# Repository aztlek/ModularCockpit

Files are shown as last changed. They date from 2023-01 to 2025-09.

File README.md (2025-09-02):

# Modular Cockpit for Star Citizen

The `Modular Cockpit` is a system of physical controls for *Star Citizen*. 

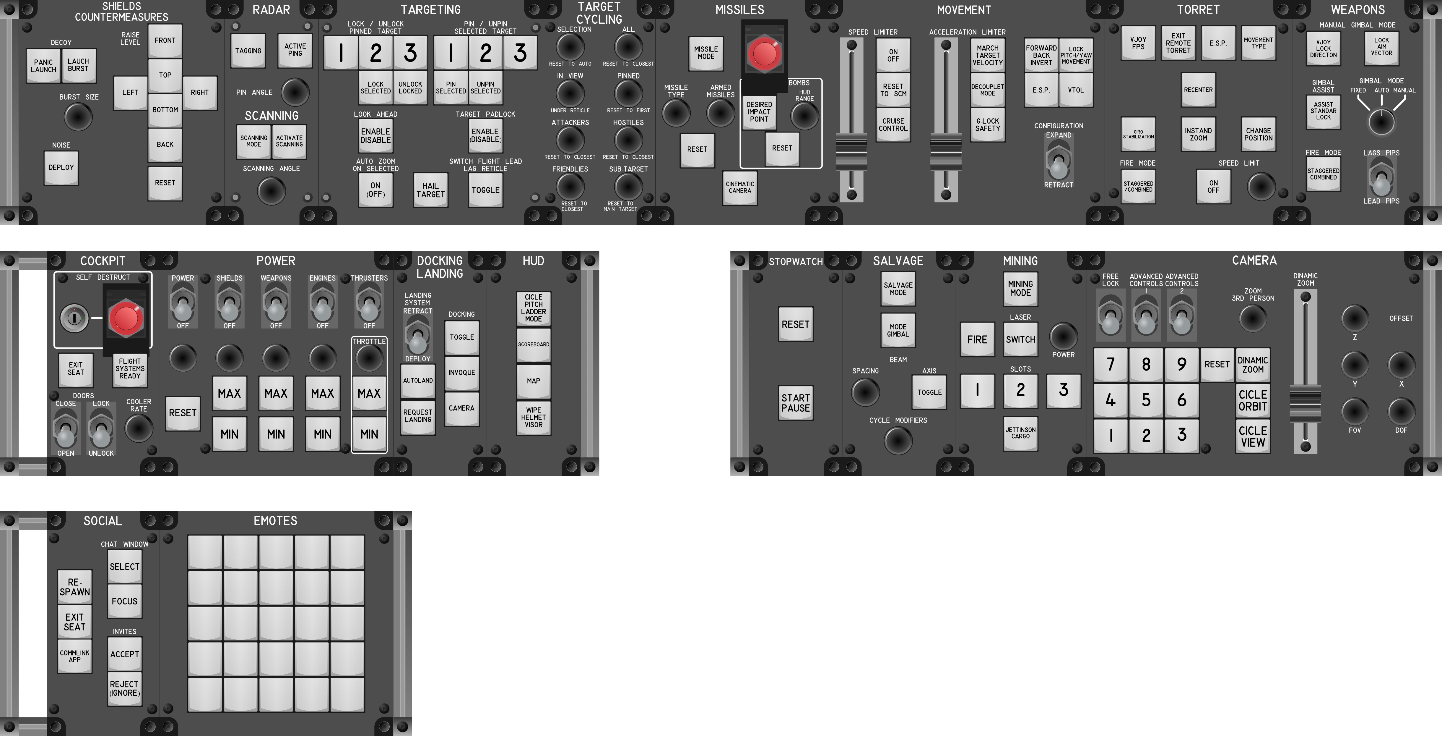
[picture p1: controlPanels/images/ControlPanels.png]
Star Citizen Modular Cockpit


It is composed of `Modules` that group several interrelated physical controls such as *switches*, *potentiometers*, *encoders*, etc. For example, the `Power Module` has several *toggle switches* to activate or deactivate power for weapons, shields, or others; it also has *encoders* to increase and decrease power, as well as buttons to quickly set maximum or minimum power.

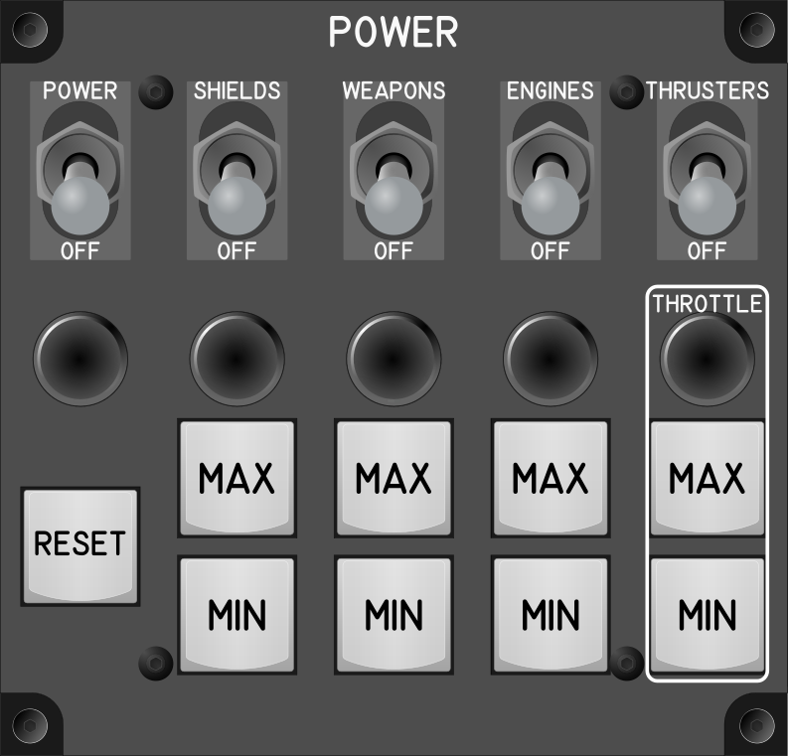
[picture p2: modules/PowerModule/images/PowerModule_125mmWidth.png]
Power Module


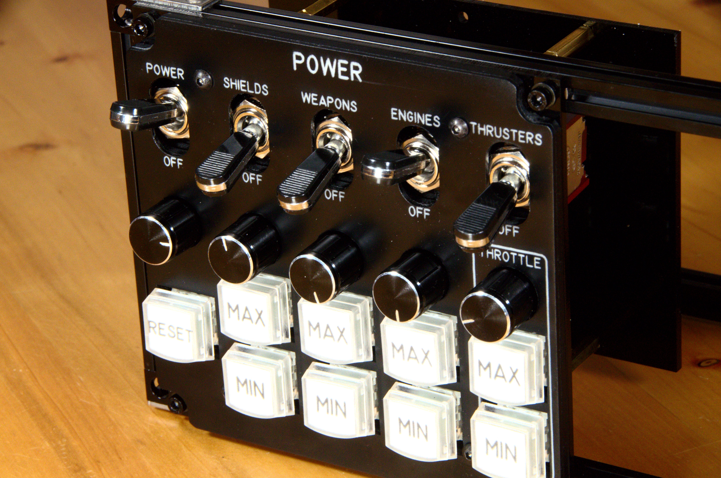
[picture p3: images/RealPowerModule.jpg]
Real Power Module


These `Modules` can be connected directly to the computer's USB port and the operating system sees them as a joystick, which makes it easy to perform *keybinding* in *Star Citizen*.

You can also `dock` several `Modules` to a `Control Panel`, which in turn connects to a computer USB port. When multiple `Modules` are docked to a `Control Panel`, the computer sees them all as a single joystick. This is very convenient when having a large number of `Modules` connected, preventing the operating system from failing in recognition and operation of multiple joysticks.

The `Modules` are interchangeable, meaning they can be swapped between `Control Panels` or positions within it. This way, the player can easily configure their cockpit depending on their playstyle.

Also, and very importantly, the `Modular Cockpit` is a free hardware and free software project. This means that anyone can download the designs and firmware, and build their own cockpit. They can also use it for whatever they want. In addition, they are free to study how the `Modular Cockpit` is made and modify it for their needs. Finally, they are free to redistribute it with or without changes as long as they state where it came from and who the authors are.

## Motivations

1. [Star Citizen](https://robertsspaceindustries.com/star-citizen/) is a game with highly enriched functionality and interactivity.
1. Each ship in *Star Citizen* can perform one or more roles.
1. Each player in *Star Citizen* can play one or more roles.
1. Each role has a particular form of interactivity.
1. Each player has a different way of playing.

Therefore, each player needs a unique cockpit adapted to their playstyle. A modular, open, and adaptable cockpit is needed for *Star Citizen*.

### Definitions

<dl>

<dt>Pilot:</dt>
<dd>The user of the <i>Modular Cockpit</i>, its very reason for existing.</dd>

<dt>Component:<dt>
<dd>The atoms that make up the <i>Modular Cockpit</i>. They can be electronic components, such as switches, potentiometers, cables, diodes, microcontrollers; or mechanical ones, such as acrylic sheets, makerbeams, etc.</dd>

<dt>Physical Control:<dt>
<dd>A type of electronic <i>Component</i> through which the <i>Pilot</i> interacts with <i>Star Citizen</i>. For example, switches, buttons, encoders, potentiometers, etc.</dd>

<dt>Module:</dt>
<dd>A grouping of physical controls and components with related functions.</dd>

<dt>Control Panel</dt>
<dd>A structure made with <a href="https://www.makerbeam.com/makerbeam/">10x10 mm Makerbeam</a> (see <i>Frame</i>) where one or several <i>Modules</i> can be <i>docked</i>.</dd>

<dt>Frame:<dt>
<dd>This is a structure built with <a href="https://www.makerbeam.com/makerbeam/">10x10 mm Makerbeam</a>. It has a height of 120 mm and the required width. For this, <a href="https://www.makerbeam.com/makerbeam-100mm-16p-black-makerbeam.html"><i>100 mm vertical beams</i></a> are used and joined to the <a href="https://www.makerbeam.com/makerbeam/10x10mm-profiles-black/"><i>horizontal beams</i></a> with <a href="https://www.makerbeam.com/makerbeam-corner-cubes-12p-black-for-makerbeam.html">MakerBeam Corner Cubes</a>. Several <a href="https://www.makerbeam.com/makerbeam-t-slot-nuts-for-makerbeam-25p.html">T-slot nuts</a> are inserted into the horizontal beams, where the <i>Modules</i> are screwed in with M3 bolts. Any other compatible system can be used. For example, the following image shows a <i>Frame</i> 220 mm wide with its different parts.</dd>

<dt>Docking a Module</dt>
<dd>Physically placing a <i>Module</i> into a <i>Control Panel</i> so that it is fixed and connected.</dd>

<dt>Undocking a Module</dt>
<dd>Removing a <i>Module</i> from the <i>Control Panel</i>, leaving the slot free.</dd>

</dl>

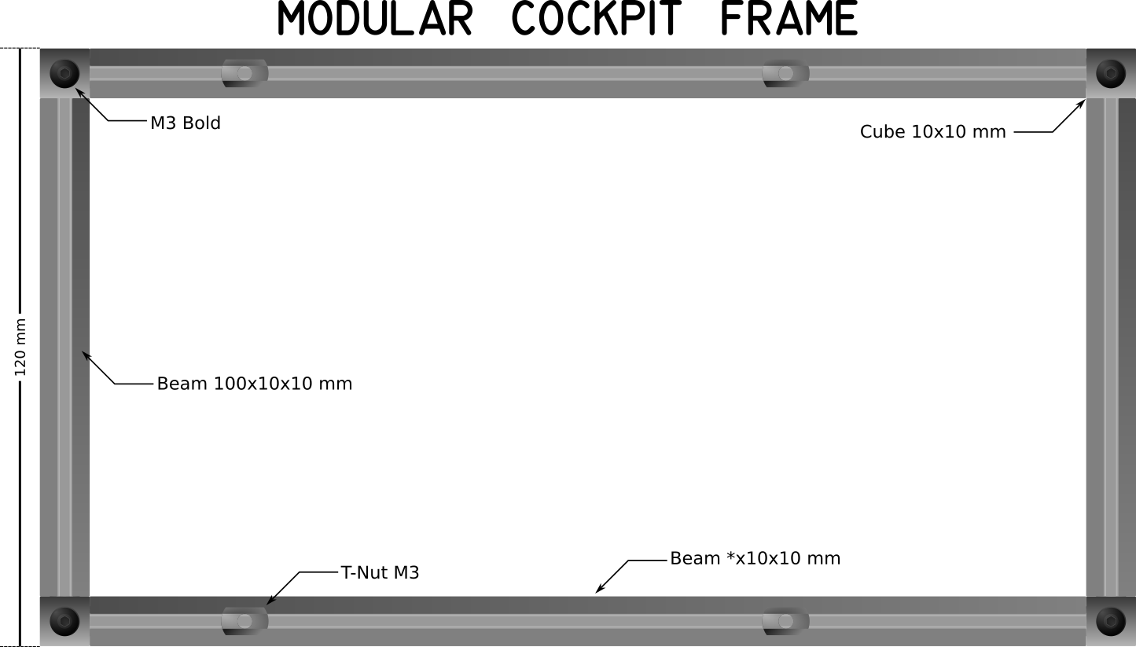
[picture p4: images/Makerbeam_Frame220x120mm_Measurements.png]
Frame with measurements


## Design Requirements

### Design Requirements for `Modules`

1. Each `Module` must work independently: it should not require other modules or elements to function, except the computer.
1. It must be interchangeable, meaning it can be placed in any `ControlPanel` and work.
1. A module must have only one cable connected to it: the USB cable.
1. A `Module` must be screwable to the `Frame` of a `ControlPanel`.
1. A module groups several related functions. The grouping of these functions must follow the categorization given in the *Keybinding* of *Star Citizen*. For example, there is a *Vehicles - Cockpit* category, so there will be at least one module that covers that category.
1. The aesthetics of the `Modules` must resemble those of military aircraft. See [The Warthod Project](https://thewarthogproject.com/) as a reference.
1. Particular functions, such as backlighting, must work within the `Module`. If there is no dedicated control for this function, it must be controllable from the computer or from a `Control Panel` independently. 

### Design Requirements for Control Panels

1. The front part of a `ControlPanel` is a `Frame` as defined above.
1. Each `ControlPanel` must have only two cables connected to it: the USB cable and the power cable.
1. The `Modules` connected to the `Control Panel` must be seen by the computer as if they were a single joystick. This avoids errors and problems caused by connecting many joysticks simultaneously.
1. A `Control Panel` can centralize particular functions of a `Module`, such as backlighting, to make global changes to these functions.
1. A `Control Panel` controls the ventilation function, which the `Modules` do not handle.

## Modules

1. [Salvage Module](modules/SalvageModule)
1. [Missiles Module](modules/MissilesModule)
1. [Docking and Landing Module](modules/DockingLandingModule)
1. [Shields and Countermeasures Module](modules/ShieldsCountermeasuresModule)
1. [Emotes Module](modules/EmotesModule)
1. [Movement Module](modules/MovementModule)
1. [Weapons Module](modules/WeaponsModule)
1. [Target Cycling Module](modules/TargetCyclingModule)
1. [Camera Module](modules/CameraModule)
1. [Stopwatch Module](modules/StopwatchModule)
1. [Power Module](modules/PowerModule)
1. [Targeting Module](modules/TargetingModule)
1. [Social Module](modules/SocialModule)
1. [Turret Module](modules/TorretModule)
1. [Mining Module](modules/MiningModule)
1. [Cockpit Module](modules/CockpitModule)
1. [Radar and Scanning Module](modules/RadarScanningModule)
1. [Hud Module](modules/HudModule)

## Input Devices

There are several types of input devices:

<dl>

<dt>Mechanical keyboard keys:</dt>
<dd>Mechanical keyboard keys are used for most SC keybindings, since SC is designed around keys.</dd>

<dt>Encoder</dt>
<dd>For cases where there are two keys, one for increasing and another for decreasing the same value, such as increasing or decreasing shield energy.</dd>

<dt>Toggle Switch (ON/OFF)</dt>
<dd>These are used when there are two keys, one to turn on and another to turn off, for example, turning shields on and off.</dd>

<dt>Linear Potentiometer</dt>
<dd>These are used for cases where SC has associated axes, or absolute changes of a value.</dd>

<dt>Joystick</dt>
<dd>Apart from obvious cases where joysticks are used, there are keybindings that by their nature should be controlled with a joystick. A joystick is essentially (at least) two orthogonal potentiometers, allowing control of two orthogonal absolute variables, such as z/y displacement of the camera.</dd>

<dt><a href="https://www.cirque.com/glidepoint-circle-trackpads">GlidePoint® Circle Trackpads</a> (like the Steam Controller)</dt>
<dd>This trackpad works very similarly to an analog joystick, so it can be used for the same purposes.</dd>

</dl>

## Microcontroller

[Teensy®](https://www.pjrc.com/teensy/) is used for the following reasons:

1. It can function as multiple HID devices simultaneously: it can be a keyboard, joystick, and mouse at the same time, in addition to working with serial. This last feature is necessary to implement a communication protocol with the modules, or in case *Star Citizen* implements something similar to *DCS-BIOS*. Being able to have both keyboard and joystick simultaneously is necessary, for example, for the ```CameraModule```, since *Star Citizen* has no way to map joystick buttons to advanced camera functions and those can only be mapped to keyboard and mouse.
1. It has many input pins. In the case of the *Teensy 4.0*, there are 40 digital pins and 14 analog ones. In the *Teensy 4.1*, there are 55 digital inputs and 18 analog ones. This is necessary since some modules require many inputs, such as the `TargetCyclingModule` with 24 digital inputs or the `PowerModule` with 30 digital inputs.
1. Furthermore, all digital inputs have interrupt capability. This makes input reading much faster. For example, the `TargetCyclingModule` with many encoders is much faster thanks to interrupt capability.
1. It also has many PWM outputs. In the case of the *Teensy 4.0*, there are 31. In the case of the *Teensy 4.1*, there are 35. This is very important for managing the backlighting of the modules.
1. The *Teensy 4.1* has a *USB Host* port used in `Control Panels` to unify the `Modules` so the operating system sees them as a single joystick.
1. It has very good speed, making the *Teensy 4.1* preferable for unifying the modules in the `ControlPanel`.
1. It also has a good amount of memory, which makes this not a concern when coding.

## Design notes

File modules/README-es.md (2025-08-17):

# Módulos

## Cómo crear un joystick personalizado especial para el modular joystick

### Adicionar un ```USB Type```al Teensy 4.0

1. Edite al archivo ```boards.txt```que se encuentra en la ruta ```~/.arduino15/packages/teensy/hardware/avr/1.59.0``` en Linux .
1. Inserte en después de la linea ```teensy40.menu.usb.flightsimjoystick.fake_serial=teensy_gateway``` las siguientes líneas:
	```
	teensy40.menu.usb.customcontroller=Modular Cockpit Joystick
	teensy40.menu.usb.customcontroller.build.usbtype=MODULAR_COCKPIT_JOYSTICK
	teensy40.menu.usb.customcontroller.upload_port.usbtype=MODULAR_COCKPIT_JOYSTICK
	```	
1. Guardar y salir

### Definir un nuevo tipo de USB

1. Edite el archivo ```usb_desc.h``` que se encuentra en la ruta ```~/.arduino15/packages/teensy/hardware/avr/1.59.0/cores/teensy4```en Linux.
1. Inserte el siguiente código antes de la línea ```#elif defined(USB_SERIAL_HID)```
	```
	 #elif defined(MODULAR_COCKPIT_JOYSTICK)
	  #define VENDOR_ID		0x16C0
	  #define PRODUCT_ID		0x0487
	  #define MANUFACTURER_NAME	{'A','z','t','l','e','k',' ','G','a','m','e','s'}
	  #define MANUFACTURER_NAME_LEN	12
	  #define PRODUCT_NAME		{'M','o','d','u','l','a','r',' ','C','o','c','k','p','i','t',' ','J','o','y','s','t','i','c','k'}
	  #define PRODUCT_NAME_LEN	24
	  #define EP0_SIZE		64
	  #define NUM_ENDPOINTS		4
	  #define NUM_INTERFACE		3
	  #define CDC_IAD_DESCRIPTOR	1
	  #define CDC_STATUS_INTERFACE	0
	  #define CDC_DATA_INTERFACE	1	// Serial
	  #define CDC_ACM_ENDPOINT	2
	  #define CDC_RX_ENDPOINT       3
	  #define CDC_TX_ENDPOINT       3
	  #define CDC_ACM_SIZE          16
	  #define CDC_RX_SIZE_480       512
	  #define CDC_TX_SIZE_480       512
	  #define CDC_RX_SIZE_12        64
	  #define CDC_TX_SIZE_12        64
	  #define JOYSTICK_INTERFACE    4	// Joystick
	  #define JOYSTICK_ENDPOINT     4
	  #define JOYSTICK_SIZE         64	//  12 = normal, 64 = extreme joystick
	  #define JOYSTICK_INTERVAL     1
	  #define ENDPOINT2_CONFIG	ENDPOINT_RECEIVE_UNUSED + ENDPOINT_TRANSMIT_INTERRUPT
	  #define ENDPOINT3_CONFIG	ENDPOINT_RECEIVE_BULK + ENDPOINT_TRANSMIT_BULK
	  #define ENDPOINT4_CONFIG	ENDPOINT_RECEIVE_UNUSED + ENDPOINT_TRANSMIT_INTERRUPT
	```
1. 	Guardar y salir.

### Crear el descriptor USB HID

No se hizo nada por que se usó el de 64, el ```extreme joystick```.

### Modificar la librería ```usb_joystick```

No se hizo nada por que se usó el de 64, el ```extreme joystick```.

### Reconfigurar y reniciar el IDE de Arduino

1. Salir del IDE de Arduino.
1. Borrar el directorio ```arduino-ide``` que está en
	1. En linux ```~/.config/arduino-ide/```
	1. En windows ```C:\Users\<user name>\AppData\Roaming\arduino-ide\ ```
	1. En MacOS ```~/Library/Application Support/arduino-ide/```
1. Reiniciar el IDE de Arduino.

### Referencias de Cómo crear un joystick personalizado

1. [Create a Custom Joystick With Teensy 4.1](https://www.instructables.com/Create-a-Custom-Joystick-With-the-Teensy-41/)
1. [Changes to custom board option definitions in boards.txt are not picked up #1030](https://github.com/arduino/arduino-ide/issues/1030#issuecomment-1152005617)

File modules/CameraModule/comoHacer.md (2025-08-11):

## How to make the Camera Module

### Bill of materials

### Corte, pintura y grabado

1. Cortar las capas usando los diagramas de corte [Cuts](images/cut/PDF)
1. Pegar la capa frontal y la media.
1. Pintar las capa frontal y media:
    1. Enmascarar con la masking tape la perte de atraz de la middle layer.
    1.  Lijar.
    1. Aplicar Primer.
    1. Pintar.
    1. Dejar secar.
1. Grabar la capa frontal pintada usando el diagrama de engrave [Engraves](images/engrave)

### Montar el Teensy 4.0 en su breakout

1. Soldar los pines
1. Colocar el Teensy en el breakout.

### Ensamblado de componentes

1. Poner los componentes en la back layer.
1. Colocar el Teensy 4.0:
    1. Soldar los pines.
    1. Colocar el Teensy en el breakout.
    1. Atornillar el breackout a la layer del microcontrolador con:
        * los 2 Button Head Socket Cap Bolts M3x12, 
        * 2 M3 Flat Washers y
        * 2 M3 Hexagon Hex Nut.

### Hacer la parte electrónica

1. Soldar los diferentes cables según el diagrama:
  Drawing Connections
1. Hacer gestión de cables con los Cable Zip Ties.

### Ensamblado del módulo

1. Ensamblar los front panels usando:
    * Front panel y Middle panel pegados.
    * Back panel.
    * 4 female to Female Thread Spacer Screws Brass Hex Standoff M3 x 60mm.
    * 4 3M Flat Washers.
    * 4 3Mx5 Button Head Socket Cap Bolts.
1. Ensamblar el microcontroler panel usando:
    * Lo que ya está essamblado del módulo.
    * 4 3M Flat Washers.
    * 4 3Mx5 Button Head Socket Cap Bolts.

### Imprimir y colocar los labels de los keycaps

1. Imprimir los labels de las keycaps usando el diagrama: [Key Labels](images/ModuleKeyLabels.pdf)
1. Ponler los labels en las keyscaps.
1. Poner las keyscaps y en las keys.

### Ensamblar en el Central Control Panel

1. Ensamblar en el Central Control Panel usando lo siguiente:
    * 4 3Mx6 Socket Head Cap Bolts.
    * 4 3M Flat Washers.

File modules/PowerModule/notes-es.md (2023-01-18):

# Modulo de potencia (PowerModule)

Power Module

El módulo de potencia tiene los controles para la de administración de la
potencia en vuelo como para los de vehículos.

## Keybindings

Los keybindingd a considerar para este módulo pertenecen a dos categorias en SC
`Vehicles – Power Triangle  Assignement` y `Flight – Power`.

### Vehicles – Power Triangle  Assignement

| Keybinding | Tipo de dispositivo de entrada |
| --- | --- |
| Weapons – Increase (tab) | encoder[0]: increase |
| Weapons – Decrease (tab) | encoder[0]: decrease |
| Weapons – Set to Max (tab) | key[0]  |
| Weapons – Set to Min (tab) | key[1] |
| Engines – Increase (tab) | encoder[1]: increase  |
| Engines – Decrease (tab) | encoder[1]: decrease |
| Engines – Set to Max (tab) | key[2] |
| Engines – Set to Min (tab) | key[3] |
| Shields – Increase (tab) | encoder[2]: increase |
| Shields – Decrease (tab) | encoder[2]: decrease |
| Shields – Set to Max (tab) | key[4] |
| Shields – Set to Min (tab) | key[5] |
| Reset Assignements | key[6] |

### Flight – Power

| Keybinding | Tipo de dispositivo de entrada |
| --- | --- |
| Set Power On | toggle_switch[0]: on |
| Set Power Off | toggle_switch[0]: off |
| Set Thrusters Power On | toggle_switch[1]: on |
| Set Thrusters Power Off | toggle_switch[1]: off |
| Set Shields Power On | toggle_switch[2]: on |
| Set Shields Power Off | toggle_switch[2]: off |
| Set Weapons Power On | toggle_switch[3]: on |
| Set Weapons Power Off | toggle_switch[3]: off |
| Increase Throttle | encoder[3]: increase |
| Decrease Throttle | encoder[3]: decrease |
| Increase Throttle to Max (double tab) | key[7] |
| Decrease Throttle to Min (double tab) | key[8] |

### Total de dispositivos usados en los keybindings

| Dispositivo | Numero |
| --- | -----: |
| Keys | 9 |
| Toggle switchs | 4 |
| Encoders | 4 |

### Categorización

La siguiente tabla organiza en dos categorias ortogonales los dispositivos de
entrada. Es una primera aproximación a como deben quedar organizados en el
panel del módulo los dispositivos de entrada.

| Power | Shields | Weapons | Engines | Thrusters | Throttle |
| :--- | :---: | :---: | :---: | :---: | :---: |
| toggle_switch | toggle_switch | toggle_switch | toggle_switch | toggle_switch | |
| | encoder | encoder | encoder | | encoder |
| | key (Max) | key (Max) | key (Max) | | key (Max) |
| | key (Min) | key (Min) | key (Min) | | key (Min) |
| key (reset) | | | | | |

## Diseño

### Consideraciones

1. Las columnas `Thrusters` y `Throttle` se fusionaron en una, pero
   marcando la diferencia entre un grupo y otro.
1. La tecla de `reset` se integra a la matriz principal de teclas debajo
   del `toggle_switch` del power.

## Componentes y procesos

Inventario de componentes y procesos para armar el módulo.

| Componente o proceso | Cantidad |
| --- | ---: |
| Keys | 9 |
| Toggle switchs | 4 |
| Encoders | 4 |
| Microcontrolador | 1 |
| Cable USB | 1 |
| Acrilico negro | 1 |
| Acrilico blanco | 1 |
| Acrilico translucido | 1 |
| Tornillos allen M3 cabeza del botón negros | ?? |
| Tornillos allen M3 cabeza de enchufe negros  | 4 |
| Standoff M3 | ?? |
| Tuercas Makerbeam | 4 |
| Cables de colores para soldar | ?? |
| Termiencogible de colores | ?? |
| Terminales para prensar los toggle switch | ?? |
| Lata de pintura negra de acrilico | 1 |
| Pegante para acrilico | 1 |
| Corte laser para los acrilicos | 3 |
| Grabado laser | 1 |

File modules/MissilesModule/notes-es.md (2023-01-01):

# Módulo de Misiles (Missiles Module)

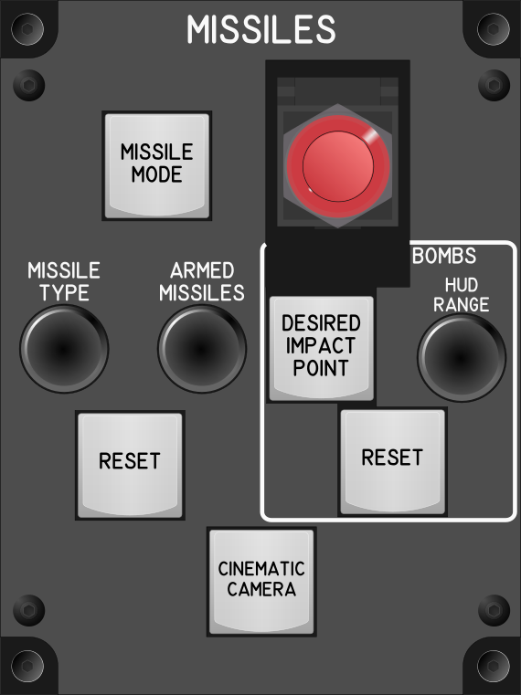
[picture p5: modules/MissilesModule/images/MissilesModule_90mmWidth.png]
Missiles Module


## Keybindings

| Keybinding | Tipo de dispositivo de entrada |
| ---| ---|
| Launch Missiles | key[0] |
| Cycle Next Missile Type | encoder[0]: increase |
| Cycle Previous Missile Type | encoder[0]: decrease |
| Increase Number of Armed Missiles | encoder[1]: increase |
| Decrease Number of Armed Missiles | encoder[1]: decrease |
| Reset Number of Armed Missiles | key[1] |
| [PH] Bombs Toggle Desired Impact Point | key[2] |
| Bombs - Increase HUD Range | encoder[2]: increase |
| Bombs – Decrease HUD Range | encoder[2]: decrease |
| Bombs – Reset HUD Range | key[3] |
| [PH] Enable Cinematic Camera (toggle)  | key[4] |

### Total de dispositivos usados en los keybindings

| Dispositivo | Numero |
| --- | -----: |
| Keys | 5 |
| Toggle switchs | 0 |
| Encoders | 3 |

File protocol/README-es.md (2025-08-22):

# Protocolo de comunicación por el serial de los modules, controlPanels e interfaz gráfica

Este protocolo se implementa sobre el serial de los módulos y de los paneles de control.

## Mensajes del Module

* Como los módulos pueden conectarse directamente al computador o mediante un ControlPanel los mensajes que le llegan son indiferentes si llegan de la interfaz gráfica o del ControlPanel. Por eso hay una columna en la siguiente tabla en el que disparador puede llegar de la interfa gráfica o del ControlPanel.
* Los mensajes de debug comienzan con una 'D' amyúscula, que viene a ser en byte 0, para diferenciarlos de los otros tipos de mensajes.

| Mensaje | Valor Byte 0 | Tipo parámetro | Valor | Disparador en el Module  | Disparador desde el ControlPanel o Interfáz Gráfica | Descripción |
| --- | ---: | --- | ----- | --- | --- | --- |
| Change_debug_mode | 1 | byte | 0,1 | Toggle Buttom | Change_debug_mode | Cambia el modo de debug 0 no debug, 1 debug |
| Change_backlight_brightness | 2 | byte | 0-255 | Potentiometer | Change_backlight_brightness | Cambia el brillo de la retroilumimación |
| Change_fan_speed | 3 | byte | 0-255 | Potentiometer | | Cambia la velocidad del ventilador. |
| Send_names | 11 | string | | | Ask_names | Envía el nombre del Module |
| Send_number_buttons | 21 | byte | 0-128 | | Ask_number | Envía el número de botones |
| Send_number_axis | 23 | byte | 0-128 | | Ask_number | Envía el número de ejes |
| Send_debug_output | 'D' | string | | | Cambio en el estado de debug a 1 | Envía mensajes de debug si el debug está activo |

## Mensajes del ControlPanel

* El brillo de los módulos puede ser cambiado desde un módulo, o desde un potenciometro conectado directamente al ControlPanel o desde la Intefaz Gráfica.
* El estado del debug puede ser cambiado desde un módulo, o desde un toggle buttom conectado directamente al Control Panel o desde la Interfaz Gráfica.
* Por lo anterior la Intefáz Gráfica debe tener una parte donde se muestren los mensajes que llegan desde el serial.
* Los mensajes de debug comienzan con una 'D' amyúscula, que viene a ser en byte 0, para diferenciarlos de los otros tipos de mensajes.

| Mensaje | Valor Byte 0 | Tipo parámetro | Valor | Disparador en el ControlPanel  | Disparador desde el Module  | Disparador desde la Interfaz Gráfica  | Descripción |
| --- | ---: | --- | ----- | --- | --- | --- | --- |
| Change_debug_mode | 1 | byte | 0,1 | Toggle Buttom | Change_debug_mode | Change_debug_mode | Cambia el modo de debug 0 no debug, 1 debug |
| Change_backlight_brightness | 2 | byte | 0-255 | Potentiometer | Change_backlight_brightness | Change_backlight_brightness | Cambia el brillo de la retroilumimación de los modules conectados a ControlPanel, o de los controlPanles conectados a la Interfaz Gráfica  |
| Change_fan_speed | 3 | byte | 0-255 | Potentiometer | Change_fan_speed | Change_fan_speed | Cambia la velocidad del ventilador. |
| Ask_names | 10 | | | setup() | | Ask_names | Pregunta por el nombre del modulo desde el control panel, o del panel desde la Interfaz Gráfica |
| Send_names | 11 | string | | | | Ask_names | Envía el nombre del panel seguida por dos puntos y una lista separada por comas de los nombres de los Modules |
| Ask_numbers | 20 | | | setup() | | Ask_number | Pregunta por el numero de componentes desde el ControlPanel, o número de modules desde la Interfáz Gráfica |
| Send_number_modules | 22 | byte | 0-9 | | | Ask_number | Envía el número de modulos coectados a ControlPanel |
| Send_debug_output | 'D' | string | | El estado de debug == 1 | | | Envía mensajes de debug si el debug está activo |

## Mensajes

### Setup modules

En el Setup se le pregunta a cada módulo su nombre, numero de teclas y de ejes.

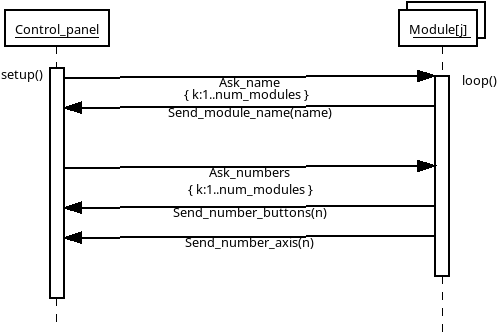
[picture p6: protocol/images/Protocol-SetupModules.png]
Setup modules


### Change_debug_mode

El mensaje Change_debug_mode cambia el modo de debug, si se envia un 1 se activa la impresión de mensajes de menú, si se envía un 0 se desactiva.

#### Change_debug_mode from Module without Control panels

El piloto cambia el estado de debug de todos los módulos conectados al computador mediante un toggle buttom que está conectado al módulo. Esto permite dos cosas: Tener un botón en cualquiera de los módulos. Tener un módulo especialisado de setup que tenga en toggle buttom de debug.

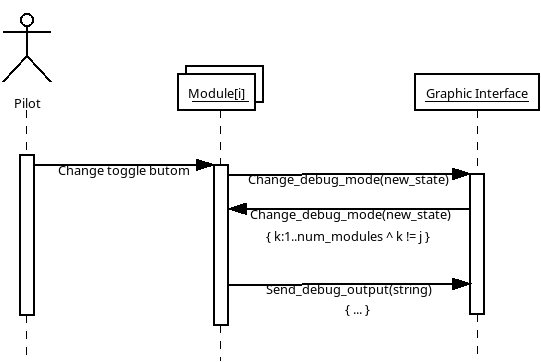
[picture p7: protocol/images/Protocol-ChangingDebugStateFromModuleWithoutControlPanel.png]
Change_debug_mode from Module without Control panel


#### Change_debug_mode from Graphic Interface without Control panels

El piloto cambia el estado de debug de todos los módulos conectados al computador, pero mediante toggle buttom en la interfaz gráfica.

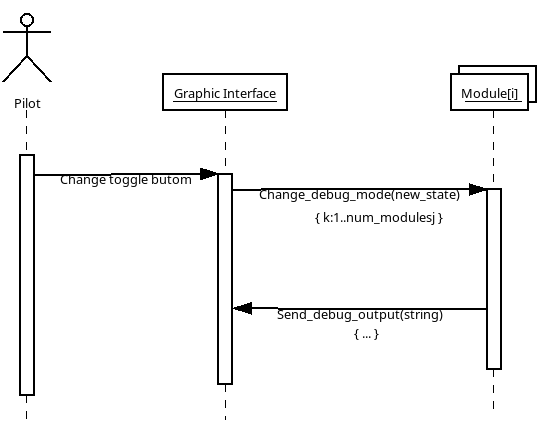
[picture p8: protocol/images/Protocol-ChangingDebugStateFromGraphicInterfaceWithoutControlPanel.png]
Change_debug_mode from Graphic Interface without Control panel


#### Change_debug_mode from Module

El piloto cambia el estado de debug de todos los módulos conectados al ControlPanel y todos los que están conectados al computador, pero mediante un toggle buttom que está conectado al Module. Si esta corriendo la interfaz gráfica cambia el estdo de todos los modulos conectados a los ControlPanels, o de los módulos conectados directo al computador.

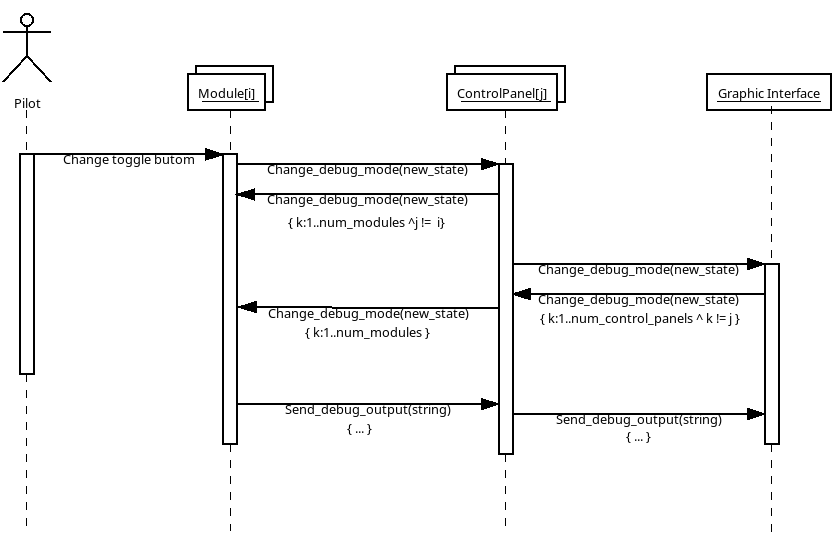
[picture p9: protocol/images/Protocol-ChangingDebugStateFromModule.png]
Change_debug_mode from Module


#### Change_debug_mode from Graphic Interface

El piloto cambia el estado de debug de todos los módulos conectados al ControlPanels que están conectados al computador, pero mediante un toggle buttom de la Interfaz Gráfica.

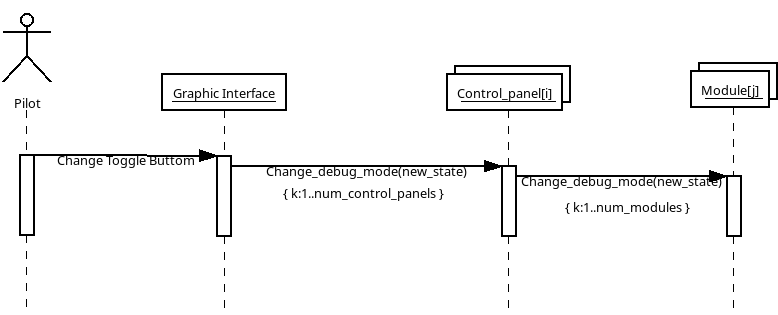
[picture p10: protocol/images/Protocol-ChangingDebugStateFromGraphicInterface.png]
Change_debug_mode from Graphic Interface


#### Change_debug_mode from ControlPanel

El piloto cambia el estado de debug de todos los módulos conectados al ControlPanel, pero mediante un toggle buttom que está conectado al ControlPanel. Si esta corriendo la interfaz gráfica cambia el estdo de todos los modulos conectados a los ControlPanels, o de los módulos conectados directo al computador.

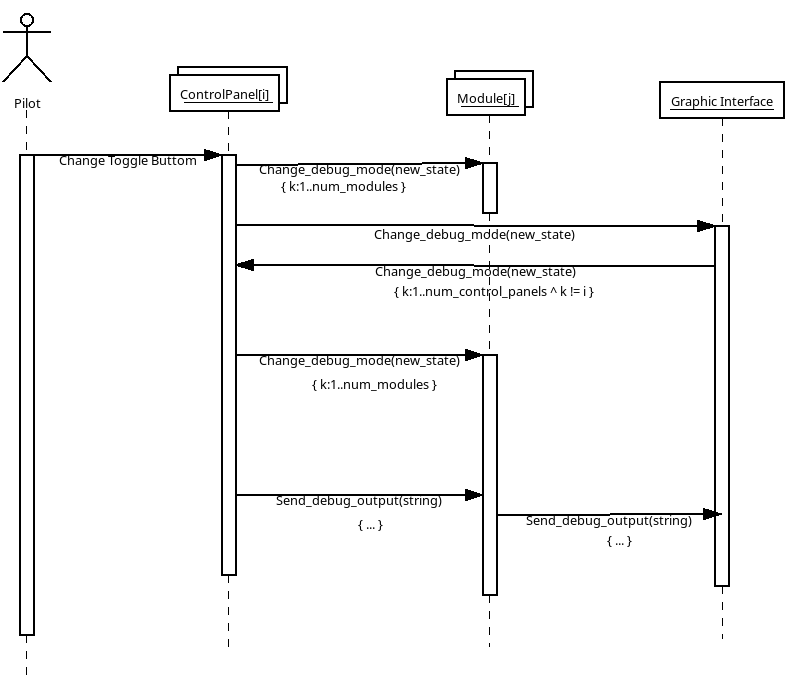
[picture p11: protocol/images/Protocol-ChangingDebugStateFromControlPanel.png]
Change_debug_mode from ControlPanel


### Change_backlight_brightness

Cambia el brillo de la retroiluminación de los módulos. La forma en como funciona este mensaje es casi igual que la de Change_debug_mode (pero sin el mensaje de Send_debug_output) por lo que no se presentam estos diagramas de interación.

### Change_fan_speed

Cambia la velocidad del el ventilador o ventiladores de ControlPanel. ESto se puede hacer mediante un potenciometro conectado directamante al ControlPanel, mediante un mensaje Change_fan_speed que llega de un módulo o de la GraphicInterface.

#### Change_fan_speed from ControlPanel

Cambia la velocidad del los ventiladores con un potenciometro conectado al ControlPanel. Sólo cambia la velocidad de sus propios ventiladores, por que los demás ControlPanels tiene diferentes necesidades de ventilación.

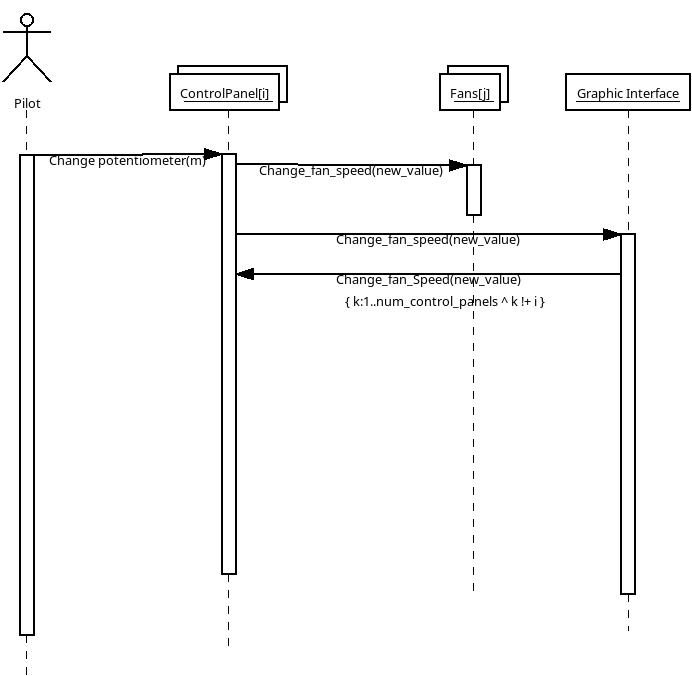
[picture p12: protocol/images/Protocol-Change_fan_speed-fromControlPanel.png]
change_fan_speed from ControlPanel


#### Change_fan_speed from GraphicInterface

Cambia la velocidad de los ventiladores de un ControlPanel selecionado en la interfaz desde la GraphicInterface. Sólo cambia la velocidad de los ventiladores de un ControlPanel selecionado, esto porque cada controlPanel tiene diferentes necesidades de ventilación.

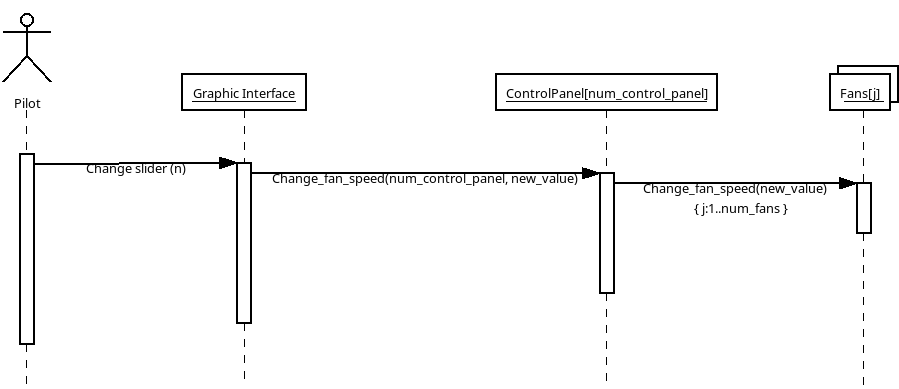
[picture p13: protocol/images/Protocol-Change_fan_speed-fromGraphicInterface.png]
Change_fan_speed from GraphicInterface


#### Change_fan_speed from Module

Cambia la velocidad del las ventiladores del ControlPanel al que está conectado el Module. Sólo cambia la velocidad de los ventiladores del ContolPanel al que está conectado el módulo, esto porque cada ControlPanel tiene sus necesidades particulares de ventilación

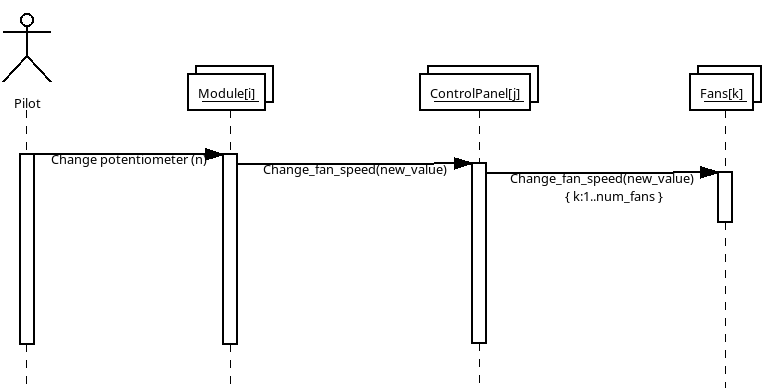
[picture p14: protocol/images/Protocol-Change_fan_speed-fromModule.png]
Change_fan_speed from Module


### Send_debug_output

Si el debug está a 1, se imprimen los mensajes de debug en el serial del módulo, y si está conectado al un ControlPanel esta los pasa con Control Panel he imprime sus propios mensajes, a contianuación la interfaz gráfica toma todos estos mensajes y los muestra. Se usa para mostar toda la informacion de paneles de control y modulos conectados.

### Ask_names

Se preguntan los nombres de los módulos y control panels con el fin de ser mostrados en la Interfa Gráfica.

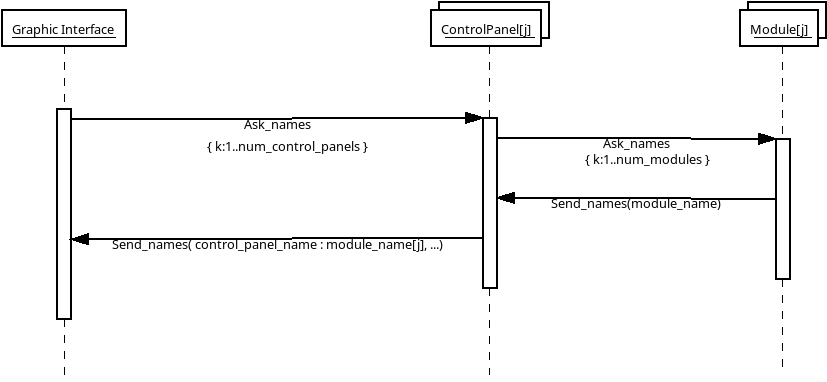
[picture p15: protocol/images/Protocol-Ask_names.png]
Ask_names


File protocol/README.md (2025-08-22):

# Serial communication protocol for modules, control panels, and graphical interfaces

This protocol is implemented over the serial port of modules and control panels.

## Module Messages

* Since modules can be connected directly to the computer or through a control panel, the messages they receive are irrelevant whether they come from the graphical interface or the control panel. Therefore, there is a column in the following table indicating which trigger can come from the graphical interface or the control panel.
* Debug messages begin with a lowercase 'D', which is byte 0, to differentiate them from other types of messages.

| Message | Byte 0 Value | Parameter Type | Value | Trigger on the Module | Trigger from the Control Panel or Graphical Interface | Description |
| --- | ---: | --- | ----- | --- | --- | --- |
| Change_debug_mode | 1 | byte | 0,1 | Toggle Button | Change_debug_mode | Changes the debug mode 0 no debug, 1 debug |
| Change_backlight_brightness | 2 | byte | 0-255 | Potentiometer | Change_backlight_brightness | Changes the backlight brightness |
| Change_fan_speed | 3 | byte | 0-255 | Potentiometer | | Change the fan speed. |
| Send_names | 11 | string | | | Ask_names | Sends the name of the Module |
| Send_number_buttons | 21 | byte | 0-128 | | Ask_number | Sends the number of buttons |
| Send_number_axis | 23 | byte | 0-128 | | Ask_number | Sends the number of axes |
| Send_debug_output | 'D' | string | | | Changes debug state to 1 | Sends debug messages if debugging is active |

## Control Panel Messages

* The brightness of the modules can be changed from a module, or from a potentiometer connected directly to the Control Panel, or from the Graphical Interface.
* The debug status can be changed from a module, or from a toggle button connected directly to the Control Panel, or from the Graphical Interface.
* Therefore, the Graphical Interface must have a section where messages arriving from the serial port are displayed.
* Debug messages begin with a lowercase 'D', which is byte 0, to differentiate them from other types of messages.

| Message | Byte 0 | Parameter Type | Value | Trigger on Control Panel | Trigger from Module | Trigger from Graphic Interface | Description |
| --- | ---: | --- | ----- | --- | --- | --- | --- |
| Change_debug_mode | 1 | byte | 0,1 | Toggle Button | Change_debug_mode | Change_debug_mode | Changes the debug mode 0 no debug, 1 debug |
| Change_backlight_brightness | 2 | byte | 0-255 | Potentiometer | Change_backlight_brightness | Change_backlight_brightness | Changes the backlight brightness of modules connected to the Control Panel, or control panels connected to the Graphic Interface |
| Change_fan_speed | 3 | byte | 0-255 | Potentiometer | Change_fan_speed | Change_fan_speed | 
| Change_fan_speed | 3 | byte | 0-255 | Potentiometer | Change_fan_speed | Change_fan_speed | Cambia la velocidad del ventilador. | |
| Ask_names | 10 | | | setup() | | Ask_names | Asks for the module name from the control panel, or the panel from the GUI |
| Send_names | 11 | string | | | | Ask_names | Sends the panel name followed by a colon and a comma-separated list of module names |
| Ask_numbers | 20 | | | setup() | | Ask_number | Asks for the number of components from the Control Panel, or the number of modules from the GUI |
| Send_number_modules | 22 | byte | 0-9 | | | Ask_number | Sends the number of modules connected to the Control Panel |
| Send_debug_output | 'D' | string | | Debug status == 1 | | | Sends debug messages if debugging is active |

## Messages

### Setup modules

In Setup, each module is asked for its name, number of keys, and axes.

Setup modules

### Change_debug_mode

The Change_debug_mode message changes the debug mode. Sending a 1 enables printing menu messages; sending a 0 disables printing.

#### Change_debug_mode from Module without Control panels

The pilot changes the debug state of all modules connected to the computer using a toggle button connected to the module. This allows two things: to have a button on any of the modules; and to have a specialized setup module that has a debug toggle button.

Change_debug_mode from Module without Control panel

#### Change_debug_mode from Graphic Interface without Control panels

The pilot changes the debug state of all modules connected to the computer, but using a toggle button on the graphical interface.

Change_debug_mode from Graphic Interface without Control panel

#### Change_debug_mode from Module

The pilot changes the debug state of all modules connected to the Control Panel and all those connected to the computer, but using a toggle button connected to the Module. If the graphical interface is running, it changes the state of all modules connected to the Control Panels, or of modules connected directly to the computer.

Change_debug_mode from Module

#### Change_debug_mode from Graphic Interface

The pilot changes the debug state of all modules connected to the Control Panels that are connected to the computer, but using a toggle button on the Graphic Interface.

Change_debug_mode from Graphic Interface

#### Change_debug_mode from ControlPanel

The pilot changes the debug state of all modules connected to the Control Panel, but using a toggle button connected to the Control Panel. If the graphical interface is running, it changes the state of all modules connected to the Control Panels, or of modules connected directly to the computer.

Change_debug_mode from ControlPanel

### Change_backlight_brightness

Changes the backlight brightness of the modules. This message works almost the same as Change_debug_mode (but without the Send_debug_output message), so these interaction diagrams are not presented.

### Change_fan_speed

Changes the speed of the ControlPanel's fan(s). This can be done using a potentiometer connected directly to the ControlPanel, using a Change_fan_speed message from a module, or using the GraphicInterface.

#### Change_fan_speed from ControlPanel

Changes the speed of the fans using a potentiometer connected to the ControlPanel. Only changes the speed of its own fans, as other ControlPanels have different ventilation requirements.

change_fan_speed from ControlPanel

#### Change_fan_speed from GraphicInterface

Changes the speed of the fans of a selected ControlPanel in the interface from the GraphicInterface. Only changes the speed of the fans of a selected ControlPanel, as each ControlPanel has different ventilation requirements.

Change_fan_speed from GraphicInterface

#### Change_fan_speed from Module

Changes the fan speed of the Control Panel to which the Module is connected. It only changes the fan speed of the Control Panel to which the Module is connected, as each Control Panel has its own specific ventilation needs.

Change_fan_speed from Module

### Send_debug_output

If debug is set to 1, debug messages are printed on the module's serial port. If it's connected to a Control Panel, it passes them to the Control Panel and prints its own messages. The graphical interface then takes all these messages and displays them. It's used to display all the information about control panels and connected modules.

### Ask_names

The names of modules and control panels are requested to be displayed in the GUI.

Ask_names

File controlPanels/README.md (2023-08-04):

# Control Panels

Control Panels

## Control Panels List

1. Center Control Panel
1. Right Control Panel
1. Left Control Panel
1. Lower Left Control Panel

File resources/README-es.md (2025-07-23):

## Instalar el tipo de letra MS33558 (US Military standard font for aircraft instrument dials)

1. Descargar de este enalace [MS33558](MS33558.ttf).
2. Hacer doble clic sobre el archivo y se instalará.

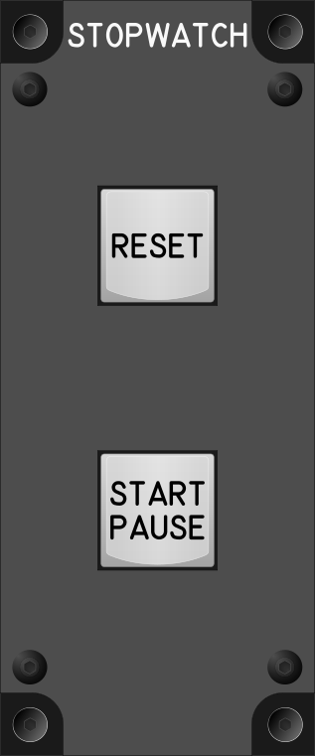
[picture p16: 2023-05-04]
modules/StopwatchModule/images/StopwatchModule_50mmWidth.png

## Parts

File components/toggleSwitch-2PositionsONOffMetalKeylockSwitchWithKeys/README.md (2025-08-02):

# Toggle Switch - 2 Positions ON Off Metal Keylock Switch With Keys

## Links

* Uxcell a11112200ux0536 Electric 2 Positions ON Off Metal Keylock Switch w Keys [Amz](https://www.amazon.com/dp/B019I12414)
* DaierTek 16mm Dustproof Safety Push Button Cap Cover Guard Plastic Protector Child Proof for 16mm Push Button Switch Computer Light Pad -2Pack [Amz](https://www.amazon.com/dp/B07VF4F9JL)

## Views

* Bottom View Bottom View
* Front View Off Front View Off
* Front View On Front View On

## Drills
 
* Back Layer Drill Layer Back Layer Drill Layer
* Middle and Front Layers Drill Middle and Front Drill

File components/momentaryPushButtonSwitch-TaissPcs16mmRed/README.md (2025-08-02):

# Momentary Push Button Switch - Taiss Pcs 16mm Red

## Links

* Taiss 2Pcs 16mm 5/8" Red Metal Momentary Push Button Switch 1NO SPST 3A/ 12-250V for Industrial Car Switch P-M16R [Amz](https://www.amazon.com/dp/B07R131RZG)

## Views

* Bottom View Bottom View
* Front View Front View

## Driils

* Back Layer Back Layer

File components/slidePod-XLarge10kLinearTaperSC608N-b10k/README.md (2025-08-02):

# SlidePod XLarge 10k Linear Taper SC608N-b10k

## Links

* Potentiometer Slide Potentiometer Knob - X-Large [Sparkfun](https://www.sparkfun.com/slide-potentiometer-knob-x-large.html)
* Knob [Amz](https://www.amazon.com/Electronics123-com-Inc-Slide-Potentiometer-Knob/dp/B01K2BZLA0)

## Views

* Front View Front View
* Botton View Botton View

## Drills

* Back Leyer Drill [Back Leyer Drill](BackLeyerDrill.svg)
* Front Leyer Drill [Front Leyer Drill](FrontLeyerDrill.svg)
* Middle Leyer Drill [Middle Leyer Drill](MiddleLeyerDrill.svg)

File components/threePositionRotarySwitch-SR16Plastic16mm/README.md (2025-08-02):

# Three Position Rotary Switch - SR16 Plastic 16mm

## Links

* 10PCS SR16 Plastic 16MM Rotary Band Switch 2 Pole 3  [Amz](https://www.amazon.com/dp/B0BRF8YTW8)

## Views

* Bottom View Bottom View
* Front View Front View

## Drills

* Back Layer Back Layer
* Front Layer Front Layer
* Middle Front Layer Middle Front Layer

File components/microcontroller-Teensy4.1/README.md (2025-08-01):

# Microcontroller - Teensy 4.0

# Links

* Teensy 4.1 [Amz: Teensy 4.1 (with Pins)](https://www.amazon.com/dp/B08CTM3279), [Amz: Teensy 4.1 ARM Cortex-M7 Processor at 600MHz with a NXP iMXRT1062 (Without pins)](https://www.amazon.com/dp/B088JY7P2H).
* Terminal Block Breakout Board Module for Teensy 4.1, Screw Mount Version [Amz: Terminal Block Breakout Board Module for Teensy 4.1, Screw Mount Version](https://www.amazon.com/dp/B08R7P8G9X).
* Terminal GPIO Breakout Board for Teensy 3.5/3.6/4.1 Module Female Pin Header 0.1" Screw Terminal 0.14" Pitch (Pack of 2) [Amz](https://www.amazon.com/dp/B0CGF11GBT)
* Breakout Board Module with Pin Board for Teensy 4.1/3.5/3.6 [Amz](https://www.amazon.com/dp/B09NXYWYK7).

## Views

* Front view with breakout and bolts Front view with breakout and bolts
* Horizontal front view with breakout and bolts Horizontal front view with breakout and bolts

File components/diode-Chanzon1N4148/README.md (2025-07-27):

# diode Chanzon 1N4148

## Views

Front View

Front View, -45 degrees

Front View, -135 degrees

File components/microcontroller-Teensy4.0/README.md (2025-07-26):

# Microcontroller - Teensy 4.0

# Views 

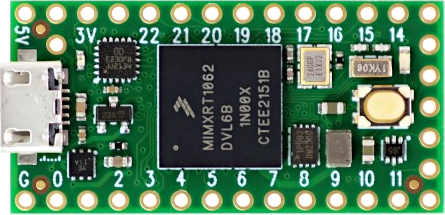
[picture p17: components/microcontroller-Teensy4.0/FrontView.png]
Front View


Front View with breaout and bolts

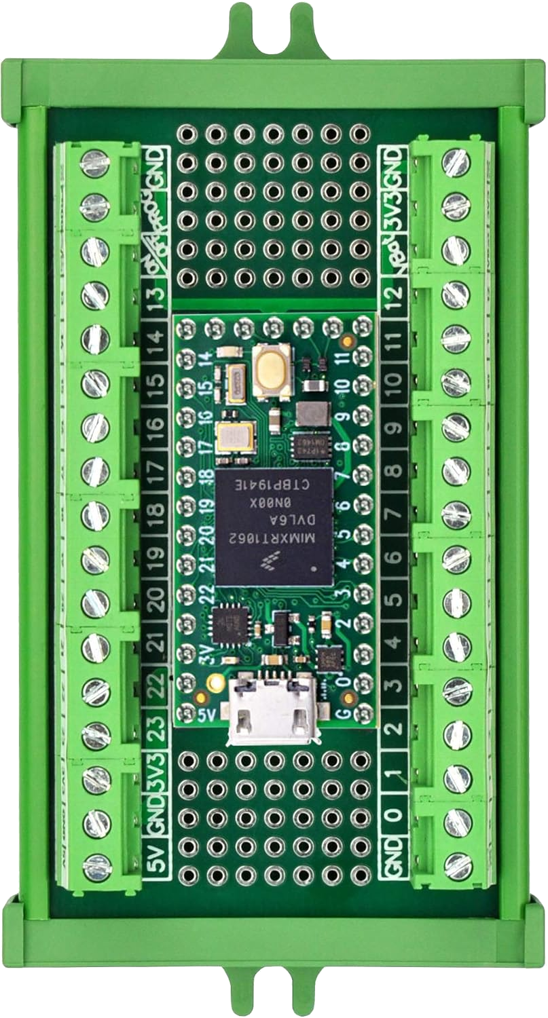
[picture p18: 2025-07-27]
components/microcontroller-Teensy4.0/FrontViewWithBreakout.png

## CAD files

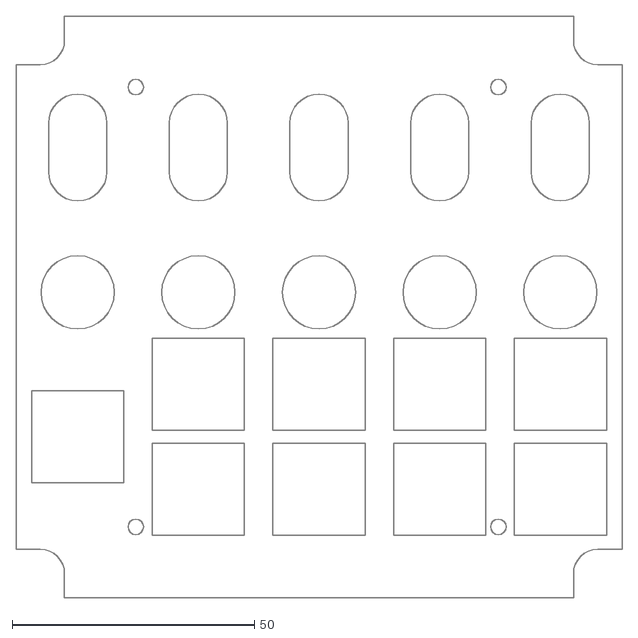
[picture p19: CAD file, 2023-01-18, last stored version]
modules/PowerModule/images/cut/DXF/2mm-White-Front_Leyer.dxf
125.0 x 119.9

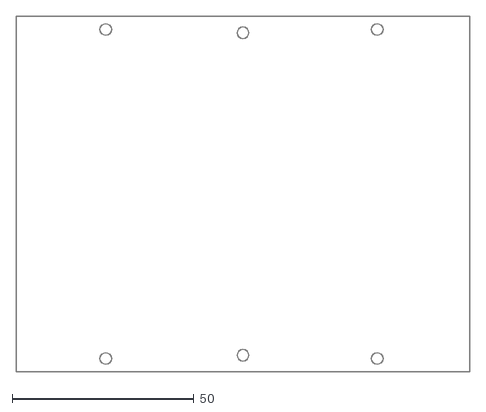
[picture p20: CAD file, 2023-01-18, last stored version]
modules/PowerModule/images/cut/DXF/3mm-Black-Microcontroller_Layer.dxf
125.0 x 97.9

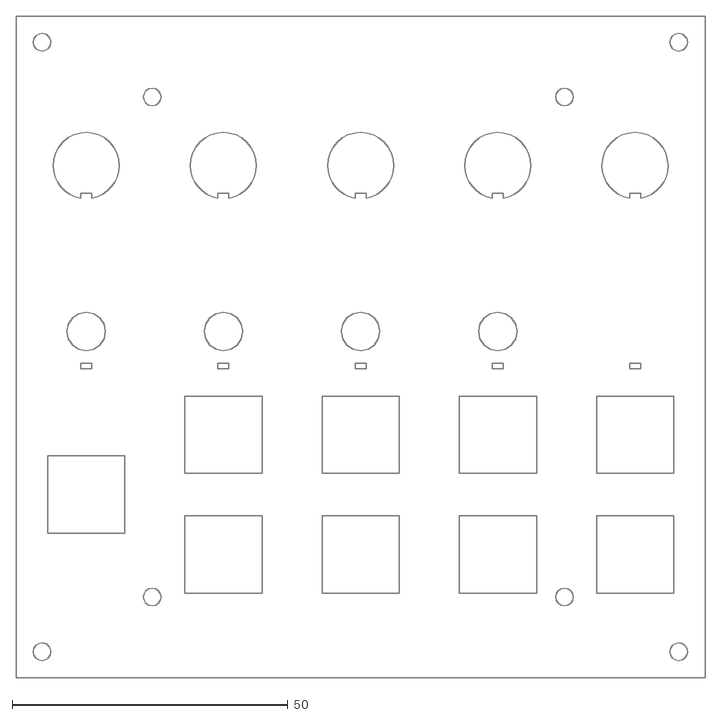
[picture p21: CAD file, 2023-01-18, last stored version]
modules/PowerModule/images/cut/DXF/3mm-Black-Back_Layer.dxf
124.9 x 119.9

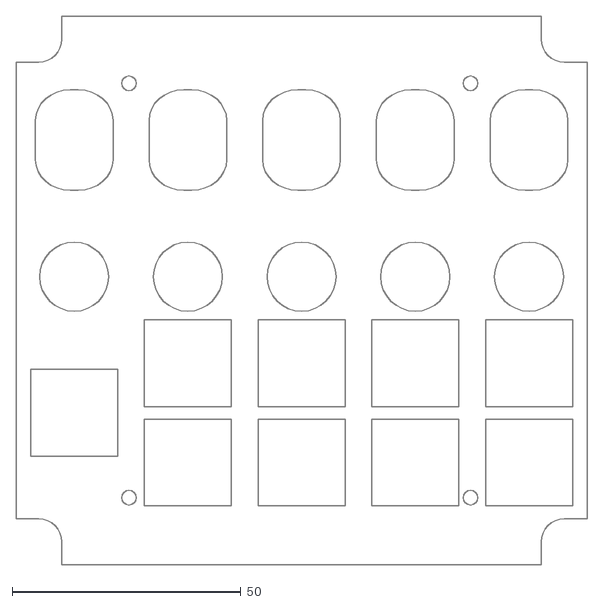
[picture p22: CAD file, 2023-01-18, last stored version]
modules/PowerModule/images/cut/DXF/3mm-Translucent-Middle_Layer.dxf
124.9 x 119.9

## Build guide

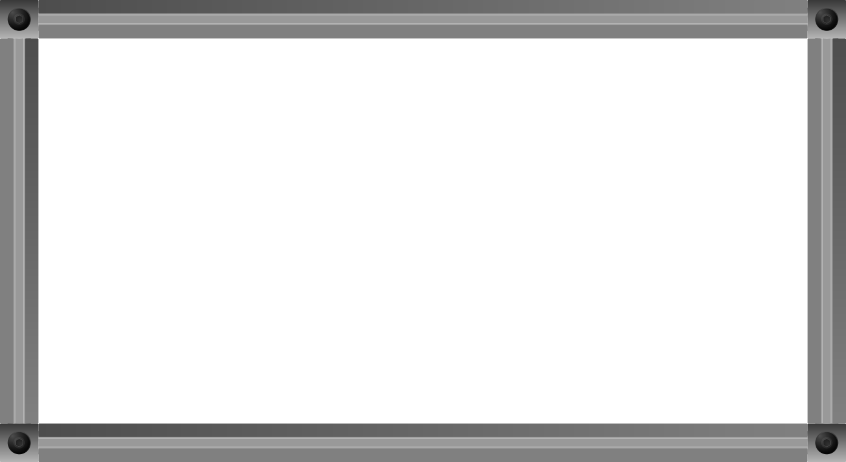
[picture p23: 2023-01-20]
images/Makerbeam_Frame220x120mm.png

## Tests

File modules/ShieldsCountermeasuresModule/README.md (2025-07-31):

# Shields and Countermeasures Module

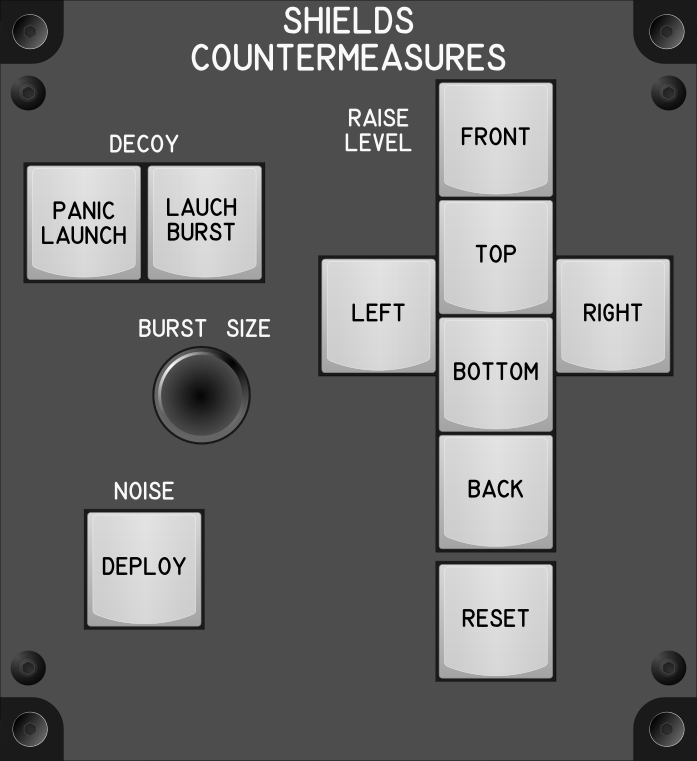
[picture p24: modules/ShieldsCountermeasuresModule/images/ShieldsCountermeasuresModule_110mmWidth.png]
Shields and Counter Measures Module


## Keybindings

### Vehicles – Shields and Countermeasures

| Keybinding | Input Device Type |
| --- | --- |
| Shield Raise level front | key[0] |
| Shield Raise level back | key[1] |
| Shield Raise level left | key[2] |
| Shield Raise level right | key[3] |
| Shield Raise level top | key[4] |
| Shield Raise level bottom | key[5] |
| Shield reset levels | key[6] |
| Decoy – Lauch Burst (tab), Set and Launch Burst (hold) | key[7] |
| Decoy – Increase Burst Size (tab) | encoder[0]: increase |
| Decoy – Increase Burst Size (tab) | encoder[0]: decrease |
| Decoy – Panic Launch (tab) | key[8] |
| Noise – Deploy (tab) | key[9] |

### Total devices in keybindings

| Device | Count  |
| --- | -----: |
| Keys | 10 |
| Toggle switchs | 0 |
| Encoders | 1 |
| Slide | 0 |
| Joystick | 0 |

## Bill of materials

| Material | Qty. | Links |
| --- | ---: | --- |
| (7 Pin 20MM)10 PCS 360 Degree EC11 Rotary Encoder Code Switch Digital Potentiometer with Caps | 1 | [Amz](https://www.amazon.com/dp/B08BFJ4F5C) |
| Jade Kailh Box Key Switches | 10 | [Amz (One Package)](https://www.amazon.com/dp/B09WYV6MTJ), [Amz (One Package)](https://www.amazon.com/dp/B0B9BDM57S) |3-com-Inc-Slide-Potentiometer-Knob/dp/B01K2BZLA0) |
| Teensy 4.0 | 1 | [Amz](https://www.amazon.com/dp/B07W5J3WNH) |
| Terminal Block Breakout Board Module for Teensy 4.0, Screw Mount Version | 1 | [Amz](https://www.amazon.com/dp/B08R7PVCFN) |
| Female to Female Thread Spacer Screws Brass Hex Standoff M3 x 60mm | 4 | [Amz](https://www.amazon.com/dp/B09V272N1N) |
| 3Mx6 Socket Head Cap Bolts | 4 | 1 package[Amz](https://www.amazon.com/dp/B00W8YSCIS) |
| 3M Flat Washers | 8 | In one package [Amz](https://www.amazon.com/dp/B08CHHLQQS) |
| 3Mx12 Button Head Socket Cap Bolts | 2 | In one package [Amz](https://www.amazon.com/dp/B08CHHLQQS) |
| 3Mx5 Button Head Socket Cap Bolts | 4 | In one package [Amz](https://www.amazon.com/dp/B08CHHLQQS) |
| Plastic Primer | 1 | [mtn](https://www.montanacolors.com/en/productos/mtn-pro-plastic-primer-spray/) |
| Black Matte Paint R-9011 | 1 | [mtn](https://www.montanacolors.com/en/productos/mtn-94-aerosol-spray-paint/) |
| 2mm white acrylic | 1 | |
| 3mm translucent acrylic | 1 | |
| 3mm black acrylic | 1 | |
| 3mm black acrylic | 1 | |

## Connections

Drawing Connections

## Key labels

[Key Labels](images/ModuleKeyLabels.pdf)

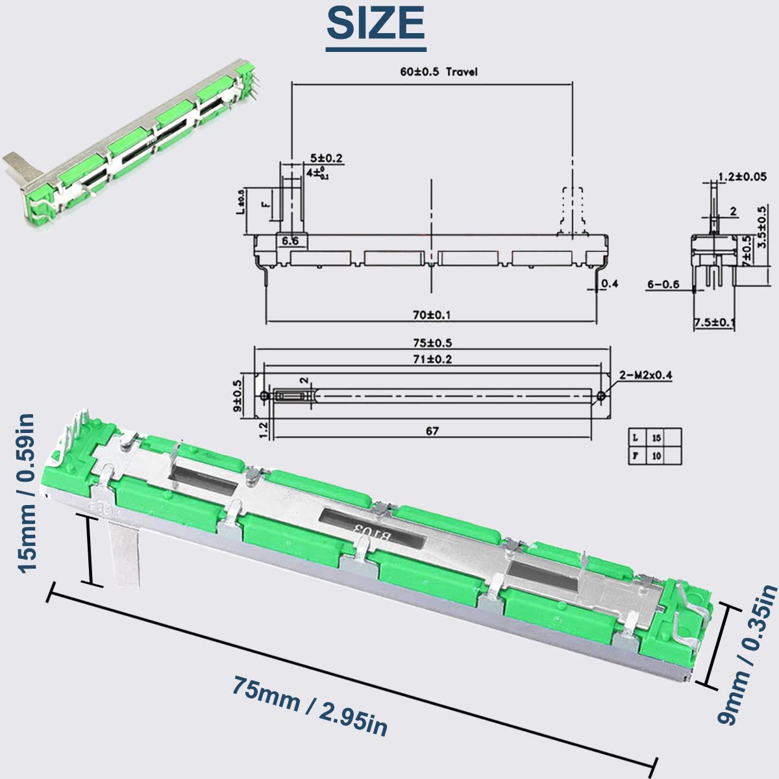
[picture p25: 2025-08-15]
components/slidePod-Taiss_10K_Double_Linear_Slide_Potentiometer_75MM_B103-10K/images/measurementDiagram.jpg

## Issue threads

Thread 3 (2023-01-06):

Design component drills and add the drills in the "Power Module"

aztlek, 2023-01-06:
- [x] bolds:
     - [x] Design the drill
     - [x] Make Standoff drills on:
         - [x] Front Layer
         - [x] Middle Layer
         - [x] Back Leyer
         - [x] Microcontroller Leyer
     - [x] Make microcontroller drills
   - [x] toggle_switch
       - [x] Front Layer
       - [x] Middle Layer
       - [x] Back Leyer
       - [x] Make drills in "PowerModule"
   - [x] key_switch
      - [x] Back Leyer
      - [x] Make drills in "PowerModule"
   - [x] key_cap
      - [x] Front Layer
      - [x] Middle Layer
      - [x] Make drills in "PowerModule"
   - [x] encoder
       - [x] Front Layer
       - [x] Middle Layer
       - [x] Back Leyer

Closed 2023-01-17.

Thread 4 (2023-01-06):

Rename component image files

aztlek, 2023-01-06:
1. Rename component image files that start with a component type identifier. For example knob, bolt, etc. The filename must begin with bold-[device].svg
1. Component image file name prefixes:
     1. bold-
     1. switch-
     1. toggle_switch-
     1. key-
     1. encoder-
     1. potentiometer-
     1. slide-
     1. joystick-
     1. led-
     1. breackout-
     1. protector-

Closed 2023-01-06.

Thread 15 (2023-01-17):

Make the "Power Module" cut files

aztlek, 2023-01-17:
Make the "Power Module" cut files for the layers:

- [x] Microcontroller Leyer: `3mm-Black-Microcontroller_Layer`:
    - [x] Plain SVG
    - [x] PDF
    - [x] DXF
- [x] Back Leyer: `3mm-Black-Back_Layer `:
    - [x] Plain SVG
    - [x] DXF
    - [x] PDF
- [x] Middle Leyer: `3mm-Translucent-Middle_Layer `:
    - [x] Plain SVG
    - [x] PDF
    - [x] DXF
- [ ] Front Leyer: `2mm-White-Front_Leyer`:
    - [ ] Plain SVG
    - [x] PDF
    - [x] DXF

Closed 2023-01-17.

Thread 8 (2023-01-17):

Redesign camera module for missing keybindings

aztlek, 2023-01-17:

aztlek, 2023-02-03:
- [ ] Redesign camera module for missing keybindings
    - [ ]  Dinamic Zoom In and Out (rel.),  slide_pot
    - [ ] Dinamic Zoom (toggle), key
    - [ ] Advanced Camera Controls Modifier (Hold), key
    - [ ] Advanced Camera Controls Modifier (Hold), key
- [ ] Up the design one level

Closed 2023-02-03.

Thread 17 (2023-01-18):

Redesign the "Power Module", it must not have more than 3 mm

aztlek, 2023-01-18:
Redesign the "Power Module", it must not have more than 3 mm of separation between perforations or borders

Closed 2023-01-18.

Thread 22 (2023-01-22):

Move the clamping bolt drills to the "Frame"

aztlek, 2023-01-22:
Move the drills of the bolts that hold the panel at least one millimeter inward on the x axis. This is so that the "t-nuts" of the "Beam" do not remain protruding from the edge of the module. This must be done in:

- [ ] Module templates
  - [ ]  50 mm
  - [ ] 60 mm
  - [ ] 70 mm
  - [ ] 80 mm
  - [ ] 90 mm
  - [ ] 100 mm
  - [ ] 110 mm
  - [ ] 120 mm
  - [ ] 125 mm
- [ ] In already designed modules:
  - [ ]  Camera
  - [ ] Cockpit
  - [ ] Dockind and Landing
  - [ ] Emotes
  - [ ] HUD
  - [ ] Mining
  - [ ] Missiles
  - [ ] Movement
  - [ ] Power
  - [ ] Radar and Scanning
  - [ ] Shields and Countermeasures
  - [ ] Torret
  - [ ] Weapons

Closed 2023-02-03.

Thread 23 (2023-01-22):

Power Module: Raise the encoders

aztlek, 2023-01-22:
Raise the encoders on the y axis because they are very close to the keys

aztlek, 2023-02-05:
- [ ] Raise the encoders

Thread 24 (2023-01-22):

Reduce the height of "Microcontroller Acrylic" to 98mm

aztlek, 2023-01-22:
This must be done in:

- [ ] Module templates
  - [ ]  50 mm
  - [ ] 60 mm
  - [ ] 70 mm
  - [ ] 80 mm
  - [ ] 90 mm
  - [ ] 100 mm
  - [ ] 110 mm
  - [ ] 120 mm
  - [ ] 125 mm
- [ ] In already designed modules:
  - [x]  Camera
  - [ ] Cockpit
  - [x] Dockind and Landing
  - [x] Emotes
  - [x] HUD
  - [ ] Mining
  - [ ] Missiles
  - [x] Movement
  - [x] Power
  - [x] Radar and Scanning
  - [ ] Shields and Countermeasures
  - [ ] Torret
  - [x] Weapons

Closed 2023-02-13.

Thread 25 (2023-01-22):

Make the labels of the keys

aztlek, 2023-01-22:
This must be done in:

  - [x]  Camera
  - [x] Cockpit
  - [x] Dockind and Landing
  - [x] Mining
  - [x] Movement
  - [x] Power
  - [x] Shields and Countermeasures
  - [x] Torret

Closed 2023-01-22.

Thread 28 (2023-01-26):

Arrange the components so that they agree with the idea of a "Modular Cockpit"

aztlek, 2023-01-26:
- [x] Move the component directory up one level in the directory hierarchy.
- [x] In the component directory make a directory for each component:
    - [x] bold-M3
        - [x]  Drill.svg
    - [x]  bolt-M3CapHead
        - [x] FrontView.svg
    - [x]  bolt-M3x8CapHead
        - [x] SiteView.svg
    - [x]  bolt-M3x12CapHead
        - [x] SiteView.svg
    - [x]  bolt-M3x16CapHead
        - [x] SiteView.svg
    - [x]  bolt-M3x20CapHead
        - [x] SiteView.svg
    - [x] bolt-M3SocketHead
        - [x] FrontView.svg
    - [x] bolt-M3x6SocketHead
        - [x] SideView.svg
    - [x] bolt-M3x8SocketHead
        - [x] SideView.svg
    - [x]  breackoutBoard-Teensy4.0ScrewMount
        - [x] FrontView.svg
        - [x] SideView.svg
    - [x] encoder-DaFuRuiEC11
        - [x] SideView.svg
        - [x] BackLayerDrill.svg
    - [x]  keyCap-XKeysKeycapCherryMX
        - [x] FrontView.svg
        - [x] FrontLayerDrill.svg
        - [x] MiddleLayerDrill.svg
   - [x]  keySwitch
        - [x] BackLeyerDrill.svg
   - [x]  keySwitch-KailhJade
        - [x] SideView.svg
   - [x]  keySwitch-KailhRed
        - [x] SideView.svg
    - [x] knop-DaFuRuiEC11
        - [x] FrontAndBackLayerDrill.svg
   - [x] knop-Uxcell-11_5mm6mmDType
        - [x] FrontView.svg
   - [x] knop-15mm
        - [x] FrontView.svg
   - [x] makerbeam10x10mm
        - [x] SideView.svg
    - [x] makerbeam10x10mm-100mmBeam
        - [x] FrontView.svg
    - [x] makerbeam10x10mm-120mmBeam
        - [x] FrontView.svg
    - [x] makerbeam10x10mm-600mmBeam
        - [x] FrontView.svg
    - [x] makerbeam10x10mm-Cube00mmBeam
        - [x] FrontView.svg
    - [x] makerbeam10x10mm-TSlot
        - [x] FrontView.svg
        - [x] SideView.svg
    - [x] makerbeamFrame-220x120mm
        - [x] FrontView.svg
    - [x] makerbeamFrame-620x120mm
        - [x] FrontView.svg
   - [x] nut-M3
        - [x] SideView.svg
   - [x] slidePod-XLarge10kLinearTaperSC608N-b10k
        - [x] FrontView.svg
        - [x] SideView.svg
   - [x] standoff-M3x5
        - [x] SideView.svg
   - [x] standoff-M3x10
        - [x] SideView.svg
   - [x] standoff-M3x15
        - [x] SideView.svg
   - [x] standoff-M3x20
        - [x] SideView.svg
   - [x] toggleSwitch-2PositionsONOffMetalKeylockSwitchWithKeys
        - [x] FrontView-Off.svg
        - [x] FrontView-On.svg
   - [x] toggleSwitch-DutyRockerToggleSwitchSPST2Position2PinOnOffSwitchWithBlackPcHandle_TEN-A-2210BK-A101
        - [x] SiteView-Off.svg
        - [x] FrontLayerDrill.svg
        - [x] MiddleLayerDrill.svg
        - [x] BackLayerDrill.svg
   - [x] toggleSwitch-ToggleSwitchSPST2PositionOnOff
        - [x] FrontView-Off.svg
        - [x] FrontView-On.svg
   - [x] toggleSwitch-TwidecRocker2Pins2PositionOnOfSPSTCarKCD3-101
        - [x] FrontView-Off.svg
        - [x] FrontView-On.svg
    - [x] washer-M3Black
        - [x] FrontView.svg
- [x] Create a templates directory to put the ModulePanels there
    - [x] ModulePanel-50mm.svg
    - [x] ModulePanel-60mm.svg
    - [x] ModulePanel-70mm.svg
    - [x] ModulePanel-80mm.svg
    - [x] ModulePanel-90mm.svg
    - [x] ModulePanel-100mm.svg
    - [x] ModulePanel-110mm.svg
    - [x] ModulePanel-120mm.svg
    - [x] ModulePanel-125mm.svg

Closed 2023-01-28.

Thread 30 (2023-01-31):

Generate the cut files

aztlek, 2023-01-31:
Generate the cut files of the modules:

- [x] (Weapons)
    - [x] Microcontroller Acrylic
        - [x] Reduce the height of the microcontroller acrylic to 98mm and center it
        - [x] 4 drills M3 Microcontroller Acrylic
        - [x] 2 drills M3 Microcontroller Acrylic Terminal Block Breakout Board
   - [x] Back Acrylic
        - [x] 4 drills M3 Microcontroller Acrylic
        - [x] drills key switchs
        - [x] 4 drills M3 Makerbeam
   - [x] Middle Acrylic
        - [x] 4 drills M3 Microcontroller Acrylic
        - [x] drills key caps
   - [x] Front Acrylic
        - [x] 4 drills M3 Microcontroller Acrylic
        - [x] drills key caps
   - [x] Generate cuts files
       - [x] Make cut directory
           - [x] Make SVG subdirectory
           - [x] Make PDF subdirectory
       - [x] 3mm-Black-Microcontroller_Layer
           - [x] 3mm-Black-Microcontroller_Layer.svg
           - [x] 3mm-Black-Microcontroller_Layer.pdf
           - [x] 3mm-Black-Back_Layer.svg
           - [x] 3mm-Black-Back_Layer.pdf
           - [x] 3mm-Translucent-Middle_Layer.svg
           - [x] 3mm-Translucent-Middle_Layer.pdf
           - [x] 2mm-White-Front_Leyer.svg
           - [x] 2mm-White-Front_Leyer.pdf

Closed 2023-02-01.

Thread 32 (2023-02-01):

Make the "Radar and Scanning Module" cut files

aztlek, 2023-02-01:
- [x] Up the design one level
- [x] Microcontroller Acrylic
    - [x] Reduce the height of the microcontroller acrylic to 98mm and center it
    - [x] 4 drills M3 from Back Bolds
    - [x] 4 drills M3 from Front Bolds
    - [x] 2 drills M3 from Terminal Block Breakout Board
- [x] Back Acrylic
    - [x] 4 drills M3 from Back Bolds
    - [x] 4 drills M3 from Front Bolds
    - [x] drills components
        - [x]  Key Switch
        - [x] Enconders
- [x] Middle Acrylic
    - [x] 4 drills M3 from Front Bolds
    - [x] drills components
        - [x]  Key Caps
        - [x] Enconders
- [x] Front Acrylic
    - [x] 4 drills M3 from Front Bolds
    - [x] drills components
        - [x]  Key Caps
        - [x] Enconders
- [x] Generate cuts files
   - [x] Make directories
       - [x] Make cut directory
           - [x] Make SVG subdirectory
           - [x] Make PDF subdirectory
   - [x] Generate Microcontroller Layer cut files
       - [x] 3mm-Black-Microcontroller_Layer.svg
       - [x] 3mm-Black-Microcontroller_Layer.pdf
   - [x] Generate Back Layer cut files
       - [x] 3mm-Black-Back_Layer.svg
       - [x] 3mm-Black-Back_Layer.pdf
   - [x] Generate Middle Layer cut files
       - [x] 3mm-Translucent-Middle_Layer.svg
       - [x] 3mm-Translucent-Middle_Layer.pdf
   - [x] Generate Front Layer cut files
       - [x] 2mm-White-Front_Leyer.svg
       - [x] 2mm-White-Front_Leyer.pdf
- [x] Generate PNG image

Closed 2023-02-06.

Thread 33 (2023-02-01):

Make the " Docking and Landing Module" cut files

aztlek, 2023-02-01:
- [x] Up the design one level
- [x] Microcontroller Acrylic
    - [x] Reduce the height of the microcontroller acrylic to 98mm and center it
    - [x] 4 drills M3 Microcontroller Acrylic
    - [x] 2 drills M3 Microcontroller Acrylic Terminal Block Breakout Board
- [x] Back Acrylic
    - [x] 4 drills M3 Microcontroller Acrylic
    - [x] drills components
        - [x]  Key Switch
        - [x] Toggle Switchs
    - [x] 4 drills M3 Makerbeam
- [x] Middle Acrylic
    - [x] 4 drills M3 Microcontroller Acrylic
    - [x] drills components
        - [x]  Key Caps
        - [x] Toggle Switchs
- [x] Front Acrylic
    - [x] 4 drills M3 Microcontroller Acrylic
    - [x] drills components
        - [x]  Key Caps
        - [x] Toggle Switchs
- [x] Generate cuts files
   - [x] Make directories
       - [x] Make cut directory
           - [x] Make SVG subdirectory
           - [x] Make PDF subdirectory
   - [x] 3mm-Black-Microcontroller_Layer
       - [x] 3mm-Black-Microcontroller_Layer.svg
       - [x] 3mm-Black-Microcontroller_Layer.pdf
       - [x] 3mm-Black-Back_Layer.svg
       - [x] 3mm-Black-Back_Layer.pdf
       - [x] 3mm-Translucent-Middle_Layer.svg
       - [x] 3mm-Translucent-Middle_Layer.pdf
       - [x] 2mm-White-Front_Leyer.svg
       - [x] 2mm-White-Front_Leyer.pdf
- [x] Generate PNG image

Closed 2023-02-06.

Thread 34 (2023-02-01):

Make the "Movement Module" cut files

aztlek, 2023-02-01:
- [x] Up the design one level
- [x] Microcontroller Acrylic
    - [x] Reduce the height of the microcontroller acrylic to 98mm and center it
    - [x] 4 drills M3 from Back Bolts
    - [x] 2 drills M3 Microcontroller Acrylic Terminal Block Breakout Board
- [x] Back Acrylic
    - [x] 4 drills M3 from Front Bolts
    - [x] 4 drills M3 from Back Bolts
    - [x] drills components
        - [x]  Key Switch
        - [x] Toggle Switchs
- [x] Middle Acrylic
    - [x] 4 drills M3 from Front Bolts
    - [x] drills components
        - [x]  Key Caps
        - [x] Toggle Switchs
- [x] Front Acrylic
    - [x] 4 drills M3 from Front Bolts
    - [x] drills components
        - [x]  Key Caps
        - [x] Toggle Switchs
- [x] Generate cuts files
   - [x] Make directories
       - [x] Make cut directory
           - [x] Make SVG subdirectory
           - [x] Make PDF subdirectory
   - [x] Generate Microcontroller Layer cut files
       - [x] 3mm-Black-Microcontroller_Layer.svg
       - [x] 3mm-Black-Microcontroller_Layer.pdf
   - [x] Generate Back Layer cut files
       - [x] 3mm-Black-Back_Layer.svg
       - [x] 3mm-Black-Back_Layer.pdf
   - [x] Generate Middle Layer cut files
       - [x] 3mm-Translucent-Middle_Layer.svg
       - [x] 3mm-Translucent-Middle_Layer.pdf
   - [x] Generate Front Layer cut files
       - [x] 2mm-White-Front_Leyer.svg
       - [x] 2mm-White-Front_Leyer.pdf
- [ ] Generate PNG image

Closed 2023-02-06.

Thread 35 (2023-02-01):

Make the "(HUD) Module" cut files

aztlek, 2023-02-01:
- [x] Up the design one level
- [x] Microcontroller Acrylic
    - [x] Reduce the height of the microcontroller acrylic to 98mm and center it
    - [x] 4 drills M3  from Front Bolds
    - [x] 2 drills M3 Microcontroller Acrylic Terminal Block Breakout Board
- [x] Back Acrylic
    - [x] 4 drills M3 from Front Bolts
    - [x] 4 drills M3 from Back Bolts
    - [x] 4 drills Key Switch
- [x] Middle Acrylic
    - [x] 4 drills M3 from Front Bolts
    - [x] 4 drills Key Caps
- [x] Front Acrylic
    - [x] 4 drills M3 from Front Bolts
    - [x] 4 drills Key Caps
- [ ] Generate cuts files
   - [x] Make directories
       - [x] Make cut directory
           - [x] Make SVG subdirectory
           - [x] Make PDF subdirectory
   - [x] Generate Microcontroller Layer cut files
       - [x] 3mm-Black-Microcontroller_Layer.svg
       - [x] 3mm-Black-Microcontroller_Layer.pdf
   - [x] Generate Back Layer cut files
       - [x] 3mm-Black-Back_Layer.svg
       - [x] 3mm-Black-Back_Layer.pdf
   - [x] Generate Middle Layer cut files
       - [x] 3mm-Translucent-Middle_Layer.svg
       - [x] 3mm-Translucent-Middle_Layer.pdf
   - [x] Generate Front Layer cut files
       - [x] 2mm-White-Front_Leyer.svg
       - [x] 2mm-White-Front_Leyer.pdf
- [x] Generate PNG image

Closed 2023-02-07.

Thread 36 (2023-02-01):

Make the "Mining Module" cut files

aztlek, 2023-02-01:
- [x] Up the design one level
- [x] Microcontroller Acrylic
    - [x] Reduce the height of the microcontroller acrylic to 98mm and center it
    - [x] 4 drills M3 from Front Bolds
    - [x] 2 drills M3  Terminal Block Breakout Board
- [x] Back Acrylic
    - [x] 4 drills M3 from Front Bolts
    - [x] 4 drills M3 from Back Bolts
    - [x] drills components
        - [x]  Key Switch
        - [x] Enconders
- [x] Middle Acrylic
    - [x] 4 drills M3 from Front Bolts
    - [x] drills components
        - [x]  Key Caps
        - [x] Enconders
- [x] Front Acrylic
    - [x] 4 drills M3 from Front Bolts
    - [x] drills components
        - [x]  Key Caps
        - [x] Enconders
- [x] Generate cuts files
   - [x] Make directories
       - [x] Make cut directory
           - [x] Make SVG subdirectory
           - [x] Make PDF subdirectory
   - [x] Generate Microcontroller Layer cut files
       - [x] 3mm-Black-Microcontroller_Layer.svg
       - [x] 3mm-Black-Microcontroller_Layer.pdf
   - [x] Generate Back Layer cut files
       - [x] 3mm-Black-Back_Layer.svg
       - [x] 3mm-Black-Back_Layer.pdf
   - [x] Generate Middle Layer cut files
       - [x] 3mm-Translucent-Middle_Layer.svg
       - [x] 3mm-Translucent-Middle_Layer.pdf
   - [x] Generate Front Layer cut files
       - [x] 2mm-White-Front_Leyer.svg
       - [x] 2mm-White-Front_Leyer.pdf
- [x] Generate PNG image

Closed 2023-02-07.

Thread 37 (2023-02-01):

Make the "(Torret) Module" cut files

aztlek, 2023-02-01:
- [x] Up the design one level
- [x]  Correct the measurements and center each of the acrylics
    - [x] Microcontroller Acrylic
    - [x] Back Acrylic
    - [x] Middle Acrylic
    - [x] Front Acrylic
- [x] Reposition the "t-slot nut"
- [x] Reposition the "Back Leyer" bolts in Back Acrylic
- [x] Erase each of the perforations in
    - [x] Microcontroller Acrylic
    - [x] Back Acrylic
    - [x] Middle Acrylic
    - [x] Front Acrylic
- [x] Make the 2 microcontroller holes
- [x] Drill the 4 holes for the Back Bolts in Back Acrylic
- [x] Drill the 4 holes for the "Front Layer" bolts in
    - [x] Microcontroller Acrylic
    - [x] Back Acrylic
    - [x] Middle Acrylic
    - [x] Front Acrylic
- [x] Make the 10 "key switch" holes in the "Back Acrylic"
- [ ] Make the 10 "key caps" perforations in
    - [x] Middle Acrylic
    - [x] Front Acrylic
- [x] Drill the "Encoder" hole in Back Acrylic
- [x] Drill the "Knob Encoder" hole in
    - [x] Middle Acrylic
    - [x] Front Acrylic
- [x] Generate cuts files
    - [x] 3mm-Black-Microcontroller_Layer.svg
    - [x] 3mm-Black-Microcontroller_Layer.pdf
    - [x] 3mm-Black-Back_Layer.svg
    - [x] 3mm-Black-Back_Layer.pdf
    - [x] 3mm-Translucent-Middle_Layer.svg
    - [x] 3mm-Translucent-Middle_Layer.pdf
    - [x] 2mm-White-Front_Leyer.svg
    - [x] 2mm-White-Front_Leyer.pdf
- [x] Generate PNG image

Closed 2023-02-13.

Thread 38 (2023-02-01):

Make the "Shields and Countermeasures Module" cut files

aztlek, 2023-02-01:
- [x] ModulePanel_80mmWidth
    - [x]  Correct the measurements and center each of the acrylics
        - [x] Microcontroller Acrylic
        - [x] Back Acrylic
        - [x] Middle Acrylic
        - [x] Front Acrylic
- [x] Create the 85mm template
    - [x]  Correct the measurements and center each of the acrylics
        - [x] Microcontroller Acrylic
        - [x] Back Acrylic
        - [x] Middle Acrylic
        - [x] Front Acrylic
- [x] Reposition the "t-slot nut"
- [x] Make the 2 microcontroller holes
- [x] Drill the 4 holes for the Back Bolts in Back Acrylic
- [x] Drill the 4 holes for the "Front Layer" bolts in
    - [x] Microcontroller Acrylic
    - [x] Back Acrylic
    - [x] Middle Acrylic
    - [x] Front Acrylic
- [x] Make the 9 "key switch" holes in the "Back Acrylic"
- [x] Make the 9 "key caps" perforations in
    - [x] Middle Acrylic
    - [x] Front Acrylic
- [x] Drill the Encoder hole in Back Acrylic
- [x] Drill the Knob Encoder hole in
    - [x] Middle Acrylic
    - [x] Front Acrylic
- [x] Generate cuts files
    - [x] 3mm-Black-Microcontroller_Layer.svg
    - [x] 3mm-Black-Microcontroller_Layer.pdf
    - [x] 3mm-Black-Back_Layer.svg
    - [x] 3mm-Black-Back_Layer.pdf
    - [x] 3mm-Translucent-Middle_Layer.svg
    - [x] 3mm-Translucent-Middle_Layer.pdf
    - [x] 2mm-White-Front_Leyer.svg
    - [x] 2mm-White-Front_Leyer.pdf
- [ ] Generate PNG image

Closed 2023-02-14.

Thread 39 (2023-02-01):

Make the "(Emotes) Module" cut files

aztlek, 2023-02-01:
- [x] Up the design one level
- [x] Modify the 125mm template so that I have the drills for the makerbeam bolts
- [x] Transfer the design to the 125 mm template to be able to put the microcontroller screws
- [x] Microcontroller Acrylic
    - [x] Reduce the height of the microcontroller acrylic to 98mm and center it
    - [ ] 4 drills M3 Microcontroller Acrylic
    - [x] 2 drills M3 Microcontroller Acrylic Terminal Block Breakout Board
- [x] Back Acrylic
    - [x] 4 drills M3 Microcontroller Acrylic
    - [x] drills key switchs
    - [x] 4 drills M3 Makerbeam
- [x] Middle Acrylic
    - [x] 4 drills M3 Microcontroller Acrylic
    - [x] drills key caps
- [x] Front Acrylic
    - [x] 4 drills M3 Microcontroller Acrylic
    - [x] drills key caps
- [x] Generate cuts files
   - [x] Mak directories
       - [x] Make cut directory
           - [x] Make SVG subdirectory
           - [x] Make PDF subdirectory
   - [x] 3mm-Black-Microcontroller_Layer
       - [x] 3mm-Black-Microcontroller_Layer.svg
       - [x] 3mm-Black-Microcontroller_Layer.pdf
       - [x] 3mm-Black-Back_Layer.svg
       - [x] 3mm-Black-Back_Layer.pdf
       - [x] 3mm-Translucent-Middle_Layer.svg
       - [x] 3mm-Translucent-Middle_Layer.pdf
       - [x] 2mm-White-Front_Leyer.svg
       - [x] 2mm-White-Front_Leyer.pdf
- [x] Generate PNG image
- [x]  Change link to image

Closed 2023-02-05.

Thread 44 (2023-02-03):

Make the "Camera Module" cut files

aztlek, 2023-02-03:
- [x] Up the design one level
- [x] Microcontroller Acrylic
    - [x] Reduce the height of the microcontroller acrylic to 98mm and center it
    - [x] 4 drills M3 Microcontroller Acrylic
    - [x] 2 drills M3 Microcontroller Acrylic Terminal Block Breakout Board
- [x] Back Acrylic
    - [x] 4 drills M3 Microcontroller Acrylic
    - [x] drills components
        - [x]  Key Switch
        - [x] Toggle Switchs
        - [x] Slide Pots
        - [x] Enconders
    - [x] 4 drills M3 Makerbeam
- [x] Middle Acrylic
    - [x] 4 drills M3 Microcontroller Acrylic
    - [x] drills components
        - [x]  Key Caps
        - [x] Toggle Switchs
        - [x] Slide Pots
        - [x] Enconders
- [x] Front Acrylic
    - [x] 4 drills M3 Microcontroller Acrylic
    - [x] drills components
        - [x]  Key Caps
        - [x] Toggle Switchs
        - [x] Slide Pots
        - [x] Enconders
- [x] Generate cuts files
   - [x] Make directories
       - [x] Make cut directory
           - [x] Make SVG subdirectory
           - [x] Make PDF subdirectory
   - [x] 3mm-Black-Microcontroller_Layer
       - [x] 3mm-Black-Microcontroller_Layer.svg
       - [x] 3mm-Black-Microcontroller_Layer.pdf
       - [x] 3mm-Black-Back_Layer.svg
       - [x] 3mm-Black-Back_Layer.pdf
       - [x] 3mm-Translucent-Middle_Layer.svg
       - [x] 3mm-Translucent-Middle_Layer.pdf
       - [x] 2mm-White-Front_Leyer.svg
       - [x] 2mm-White-Front_Leyer.pdf
- [x] Generate PNG image
- [x]  Change link to image
- [x] Update matrix

Closed 2023-02-06.

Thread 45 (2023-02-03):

Redesign the "Camera Module" for a width of 155 mm

aztlek, 2023-02-03:
- [ ] Make a 155mm module template
- [ ] Move the "Module Camera" to 150mm

Closed 2023-02-04.

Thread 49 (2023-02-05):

Redesign the "Camera Module" taking into account the hold keys

aztlek, 2023-02-05:
Assuming that a microcontroller can be configured at the same time as joystick and keyboard.

- [x] Design 180 mm template
- [x] Change keys to "Toggle Switches"
    - [x] Freelock (Hold)
    - [x] Advanced Camera Controls Modifier 1 (Hold)
    - [x] Advanced Camera Controls Modifier 2 (Hold)
- [x] Change the "Slide Pot" to "Encoder" (this because the keybindings in SC are as keys and not as axes) in
    - [x] Zoom in (3rd person view)
    - [x] Zoom out (3rd person view)
- [x] Change the position of the x axis encoder, so that it is at the same level as the y axis
- [x] Regenerate the png
- [x] Change the link in the `README.md`
- [x] Put the new version in `ModularCockpit_620x120mm.svg`
    - [x] Regenerate the png
- [x] Put the new version in the matrix
    - [x] Regenerate the png

Closed 2023-02-05.

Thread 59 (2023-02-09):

Docking and Landing Module: Perforations are slightly offset

aztlek, 2023-02-09:
- [x]  Correct the measurements and center each of the acrylics
    - [x] Microcontroller Acrylic
    - [x] Back Acrylic
    - [x] Middle Acrylic
    - [x] Front Acrylic
- [x] Reposition the "t-slot nut" and reposition the "Back Leyer" bolts in Back Acrylic
- [x] Erase each of the perforations in
    - [x] Microcontroller Acrylic
    - [x] Back Acrylic
    - [x] Middle Acrylic
    - [x] Front Acrylic
- [x] Make the 2 microcontroller holes
- [x] Drill the 4 holes for the "Back Layer" bolts in
    - [x] Microcontroller Acrylic
    - [x] Back Acrylic
- [x] Drill the 4 holes for the "Front Layer" bolts in
    - [x] Microcontroller Acrylic
    - [x] Back Acrylic
    - [x] Middle Acrylic
    - [x] Front Acrylic
- [x] Make the 5 "key switch" holes in the "Back Acrylic"
- [x] Make the 5 "key caps" perforations in
    - [x] Middle Acrylic
    - [x] Front Acrylic
- [x] Drill the "Toggle Switch" hole in
    - [x] Back Acrylic
    - [x] Middle Acrylic
    - [x] Front Acrylic
- [x] Generate cuts files
    - [x] 3mm-Black-Microcontroller_Layer.svg
    - [x] 3mm-Black-Microcontroller_Layer.pdf
    - [x] 3mm-Black-Back_Layer.svg
    - [x] 3mm-Black-Back_Layer.pdf
    - [x] 3mm-Translucent-Middle_Layer.svg
    - [x] 3mm-Translucent-Middle_Layer.pdf
    - [x] 2mm-White-Front_Leyer.svg
    - [x] 2mm-White-Front_Leyer.pdf
- [x] Generate PNG image

Closed 2023-02-10.

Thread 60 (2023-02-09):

Emotes Module: Perforations are slightly offset

aztlek, 2023-02-09:
- [x]  Correct the measurements and center each of the acrylics
    - [x] Microcontroller Acrylic
    - [x] Back Acrylic
    - [x] Middle Acrylic
    - [x] Front Acrylic
- [x] Reposition the "t-slot nut"
- [x] Reposition the "Back Leyer" bolts in Back Acrylic
- [x] Erase each of the perforations in
    - [x] Microcontroller Acrylic
    - [x] Back Acrylic
    - [x] Middle Acrylic
    - [x] Front Acrylic
- [x] Make the 2 microcontroller holes
- [x] Drill the 4 holes for the Back Bolts in Back Acrylic
- [x] Drill the 4 holes for the "Front Layer" bolts in
    - [x] Microcontroller Acrylic
    - [x] Back Acrylic
    - [x] Middle Acrylic
    - [x] Front Acrylic
- [x] Make the 25 "key switch" holes in the "Back Acrylic"
- [x] Make the 25 "key caps" perforations in
    - [x] Middle Acrylic
    - [x] Front Acrylic
- [x] Generate cuts files
    - [x] 3mm-Black-Microcontroller_Layer.svg
    - [x] 3mm-Black-Microcontroller_Layer.pdf
    - [x] 3mm-Black-Back_Layer.svg
    - [x] 3mm-Black-Back_Layer.pdf
    - [x] 3mm-Translucent-Middle_Layer.svg
    - [x] 3mm-Translucent-Middle_Layer.pdf
    - [x] 2mm-White-Front_Leyer.svg
    - [x] 2mm-White-Front_Leyer.pdf
- [x] Generate PNG image

Closed 2023-02-13.

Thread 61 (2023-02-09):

Mining Module: Perforations are slightly offset

aztlek, 2023-02-09:
- [x]  Correct the measurements and center each of the acrylics
    - [x] Microcontroller Acrylic
    - [x] Back Acrylic
    - [x] Middle Acrylic
    - [x] Front Acrylic
- [x] Reposition the "t-slot nut"
- [x] Reposition the "Back Leyer" bolts in Back Acrylic
- [x] Erase each of the perforations in
    - [x] Microcontroller Acrylic
    - [x] Back Acrylic
    - [x] Middle Acrylic
    - [x] Front Acrylic
- [x] Make the 2 microcontroller holes
- [x] Drill the 4 holes for the Back Bolts in Back Acrylic
- [x] Drill the 4 holes for the "Front Layer" bolts in
    - [x] Microcontroller Acrylic
    - [x] Back Acrylic
    - [x] Middle Acrylic
    - [x] Front Acrylic
- [x] Make the 7 "key switch" holes in the "Back Acrylic"
- [x] Make the 7 "key caps" perforations in
    - [x] Middle Acrylic
    - [x] Front Acrylic
- [x] Drill the "Encoder" hole in Back Acrylic
- [x] Drill the "Knob Encoder" hole in
    - [x] Middle Acrylic
    - [x] Front Acrylic
- [x] Generate cuts files
    - [x] 3mm-Black-Microcontroller_Layer.svg
    - [x] 3mm-Black-Microcontroller_Layer.pdf
    - [x] 3mm-Black-Back_Layer.svg
    - [x] 3mm-Black-Back_Layer.pdf
    - [x] 3mm-Translucent-Middle_Layer.svg
    - [x] 3mm-Translucent-Middle_Layer.pdf
    - [x] 2mm-White-Front_Leyer.svg
    - [x] 2mm-White-Front_Leyer.pdf
- [x] Generate PNG image

Closed 2023-02-13.

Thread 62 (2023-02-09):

Radar and Scanning Module: Perforations are slightly offset

aztlek, 2023-02-09:
- [x]  Correct the measurements and center each of the acrylics
    - [x] Microcontroller Acrylic
    - [x] Back Acrylic
    - [x] Middle Acrylic
    - [x] Front Acrylic
- [x] Reposition the "t-slot nut"
- [x] Reposition the "Back Leyer" bolts in Back Acrylic
- [x] Erase each of the perforations in
    - [x] Microcontroller Acrylic
    - [x] Back Acrylic
    - [x] Middle Acrylic
    - [x] Front Acrylic
- [x] Make the 2 microcontroller holes
- [x] Drill the 4 holes for the Back Bolts in Back Acrylic
- [x] Drill the 4 holes for the "Front Layer" bolts in
    - [x] Back Acrylic
    - [x] Middle Acrylic
    - [x] Front Acrylic
- [x] Make the 3 "key switch" holes in the "Back Acrylic"
- [x] Make the 3 "key caps" perforations in
    - [x] Middle Acrylic
    - [x] Front Acrylic
- [x] Drill the 2 encoders in Back Acrylic
- [x] Drill the 2 encoders knob in
    - [x] Middle Acrylic
    - [x] Front Acrylic
- [x] Generate cuts files
    - [x] 3mm-Black-Microcontroller_Layer.svg
    - [x] 3mm-Black-Microcontroller_Layer.pdf
    - [x] 3mm-Black-Back_Layer.svg
    - [x] 3mm-Black-Back_Layer.pdf
    - [x] 3mm-Translucent-Middle_Layer.svg
    - [x] 3mm-Translucent-Middle_Layer.pdf
    - [x] 2mm-White-Front_Leyer.svg
    - [x] 2mm-White-Front_Leyer.pdf
- [x] Generate PNG image

Closed 2023-02-13.

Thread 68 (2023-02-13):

Make the cut files of the "Radar and Scanning Module"

aztlek, 2023-02-13:
- [ ] Up the design one level
- [ ]  Correct the measurements and center each of the acrylics
    - [ ] Microcontroller Acrylic
    - [ ] Back Acrylic
    - [ ] Middle Acrylic
    - [ ] Front Acrylic
- [ ] Reposition the "t-slot nut"
- [ ] Reposition the "Back Leyer" bolts in Back Acrylic
- [ ] Erase each of the perforations in
    - [ ] Microcontroller Acrylic
    - [ ] Back Acrylic
    - [ ] Middle Acrylic
    - [ ] Front Acrylic
- [ ] Make the 2 microcontroller holes
- [ ] Drill the 4 holes for the Back Bolts in Back Acrylic
- [ ] Drill the 4 holes for the "Front Layer" bolts in
    - [ ] Microcontroller Acrylic
    - [ ] Back Acrylic
    - [ ] Middle Acrylic
    - [ ] Front Acrylic
- [ ] Make the 3 "key switch" holes in the "Back Acrylic"
- [ ] Make the 3 "key caps" perforations in
    - [ ] Middle Acrylic
    - [ ] Front Acrylic
- [ ] Drill the 2 Encoders hole in Back Acrylic
- [ ] Drill the 2 Knob Encoders hole in
    - [ ] Middle Acrylic
    - [ ] Front Acrylic
- [ ] Generate cuts files
    - [ ] 3mm-Black-Microcontroller_Layer.svg
    - [ ] 3mm-Black-Microcontroller_Layer.pdf
    - [ ] 3mm-Black-Back_Layer.svg
    - [ ] 3mm-Black-Back_Layer.pdf
    - [ ] 3mm-Translucent-Middle_Layer.svg
    - [ ] 3mm-Translucent-Middle_Layer.pdf
    - [ ] 2mm-White-Front_Leyer.svg
    - [ ] 2mm-White-Front_Leyer.pdf
- [ ] Generate PNG image
- [ ]  Change link to image into `images/ModularCokpit_620x120mm.svg`

Closed 2023-02-14.

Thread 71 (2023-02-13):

Make the cut files of the "Movement Module"

aztlek, 2023-02-13:
- [ ] Up the design one level
- [ ]  Correct the measurements and center each of the acrylics
    - [ ] Microcontroller Acrylic
    - [ ] Back Acrylic
    - [ ] Middle Acrylic
    - [ ] Front Acrylic
- [ ] Reposition the "t-slot nut"
- [ ] Reposition the "Back Leyer" bolts in Back Acrylic
- [ ] Erase each of the perforations in
    - [ ] Microcontroller Acrylic
    - [ ] Back Acrylic
    - [ ] Middle Acrylic
    - [ ] Front Acrylic
- [ ] Make the 2 microcontroller holes
- [ ] Drill the 4 holes for the Back Bolts in Back Acrylic
- [ ] Drill the 4 holes for the "Front Layer" bolts in
    - [ ] Microcontroller Acrylic
    - [ ] Back Acrylic
    - [ ] Middle Acrylic
    - [ ] Front Acrylic
- [ ] Make the 4 "key switch" holes in the "Back Acrylic"
- [ ] Make the 4 "key caps" perforations in
    - [ ] Middle Acrylic
    - [ ] Front Acrylic
- [ ] Drill the  toggle switch in
    - [ ] Back Acrylic
    - [ ] Middle Acrylic
    - [ ] Front Acrylic
- [ ] Generate cuts files
    - [ ] 3mm-Black-Microcontroller_Layer.svg
    - [ ] 3mm-Black-Microcontroller_Layer.pdf
    - [ ] 3mm-Black-Back_Layer.svg
    - [ ] 3mm-Black-Back_Layer.pdf
    - [ ] 3mm-Translucent-Middle_Layer.svg
    - [ ] 3mm-Translucent-Middle_Layer.pdf
    - [ ] 2mm-White-Front_Leyer.svg
    - [ ] 2mm-White-Front_Leyer.pdf
- [ ] Generate PNG image
- [ ]  Change link to image into `images/ModularCokpit_620x120mm.svg`

Closed 2023-02-14.

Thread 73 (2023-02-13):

Redesign the "Cockpit Module" with the new red switch

aztlek, 2023-02-13:

Closed 2023-02-14.

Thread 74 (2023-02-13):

Redesign the "Missiles Module" with the new red switch

aztlek, 2023-02-13:

Closed 2023-02-14.

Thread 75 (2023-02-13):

Design Red Momentary Push Button Switch drilling

aztlek, 2023-02-13:
Design Red Momentary Push Button Switch drilling in:
- [x] Back Acrylic
- [x] Middle Acrylic
- [x] Front Acrylic

Closed 2023-02-14.

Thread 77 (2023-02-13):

Make the cut files of the "Cockpit Module"

aztlek, 2023-02-13:
- [x] Up the design one level
- [x]  Correct the measurements and center each of the acrylics
    - [x] Microcontroller Acrylic
    - [x] Back Acrylic
    - [x] Middle Acrylic
    - [x] Front Acrylic
- [x] Reposition the "t-slot nut"
- [x] Reposition the "Back Leyer" bolts in Back Acrylic
- [x] Erase each of the perforations in
    - [x] Microcontroller Acrylic
    - [x] Back Acrylic
    - [x] Middle Acrylic
    - [x] Front Acrylic
- [x] Make the 2 microcontroller holes
- [x] Drill the 4 holes for the Back Bolts in Back Acrylic
- [x] Drill the 4 holes for the "Front Layer" bolts in
    - [x] Microcontroller Acrylic
    - [x] Back Acrylic
    - [x] Middle Acrylic
    - [x] Front Acrylic
- [x] Make the 2 "key switch" holes in the "Back Acrylic"
- [x] Make the 2 "key caps" perforations in
    - [x] Middle Acrylic
    - [x] Front Acrylic
- [x] Drill the "Encoder" hole in Back Acrylic
- [x] Drill the "Knob Encoder" hole in
    - [x] Middle Acrylic
    - [x] Front Acrylic
- [x] Drill the 2 toggle switchs in
    - [x] Back Acrylic
    - [x] Middle Acrylic
    - [x] Front Acrylic
- [x] Drill the Red Momentary Push Button Switch in
    - [x] Back Acrylic
    - [x] Middle Acrylic
    - [x] Front Acrylic
- [x] Drill the keylock Switch in
    - [x] Back Acrylic
    - [x] Middle Acrylic
    - [x] Front Acrylic
- [x] Generate cuts files
    - [x] 3mm-Black-Microcontroller_Layer.svg
    - [x] 3mm-Black-Microcontroller_Layer.pdf
    - [x] 3mm-Black-Back_Layer.svg
    - [x] 3mm-Black-Back_Layer.pdf
    - [x] 3mm-Translucent-Middle_Layer.svg
    - [x] 3mm-Translucent-Middle_Layer.pdf
    - [x] 2mm-White-Front_Leyer.svg
    - [x] 2mm-White-Front_Leyer.pdf
- [x] Generate PNG image

Closed 2023-02-14.

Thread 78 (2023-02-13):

Make the cut files of the "Missiles Module"

aztlek, 2023-02-13:
- [x] Up the design one level
- [x]  Correct the measurements and center each of the acrylics
    - [x] Microcontroller Acrylic
    - [x] Back Acrylic
    - [x] Middle Acrylic
    - [x] Front Acrylic
- [x] Reposition the "t-slot nut"
- [x] Reposition the "Back Leyer" bolts in Back Acrylic
- [x] Erase each of the perforations in
    - [x] Microcontroller Acrylic
    - [x] Back Acrylic
    - [x] Middle Acrylic
    - [x] Front Acrylic
- [x] Make the 2 microcontroller holes
- [x] Drill the 4 holes for the Back Bolts in Back Acrylic
- [x] Drill the 4 holes for the "Front Layer" bolts in
    - [x] Microcontroller Acrylic
    - [x] Back Acrylic
    - [x] Middle Acrylic
    - [x] Front Acrylic
- [x] Make the 5 "key switch" holes in the "Back Acrylic"
- [x] Make the 5 "key caps" perforations in
    - [x] Middle Acrylic
    - [x] Front Acrylic
- [x] Drill the 3 Encoders hole in Back Acrylic
- [x] Drill the 3 Knob Encoders hole in
    - [x] Middle Acrylic
    - [x] Front Acrylic
- [x] Drill the Red Momentary Push Button Switch in
    - [x] Back Acrylic
    - [x] Middle Acrylic
    - [x] Front Acrylic
- [x] Generate cuts files
    - [x] 3mm-Black-Microcontroller_Layer.svg
    - [x] 3mm-Black-Microcontroller_Layer.pdf
    - [x] 3mm-Black-Back_Layer.svg
    - [x] 3mm-Black-Back_Layer.pdf
    - [x] 3mm-Translucent-Middle_Layer.svg
    - [x] 3mm-Translucent-Middle_Layer.pdf
    - [x] 2mm-White-Front_Leyer.svg
    - [x] 2mm-White-Front_Leyer.pdf
- [x] Generate PNG image

Closed 2023-02-14.

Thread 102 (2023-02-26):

Fix color on "Momentary Red Push Button Switch"

aztlek, 2023-02-26:
- [x] Modify the "Cockpit Module" with the new button
- [x] Modify the "ModularCockpit_620x120mm" with the new "Cockpit Module"
- [x] Modify the "Missile Module" with the new button

Closed 2023-02-26.

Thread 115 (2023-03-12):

Correct dimensions of the Mining Module

aztlek, 2023-03-12:
- [x]  Correct the measurements and center each of the acrylics
    - [x] Microcontroller Acrylic
    - [x] Back Acrylic
    - [x] Middle Acrylic
    - [x] Front Acrylic
- [x] Reposition the "t-slot nut"
- [x] Reposition the "Back Leyer" bolts in Back Acrylic
- [x] Erase each of the perforations in
    - [x] Microcontroller Acrylic
    - [x] Back Acrylic
    - [x] Middle Acrylic
    - [x] Front Acrylic
- [x] Make the 2 microcontroller holes
- [x] Drill the 4 holes for the Back Bolts in Back Acrylic
- [x] Drill the 4 holes for the "Front Layer" bolts in
    - [x] Microcontroller Acrylic
    - [x] Back Acrylic
    - [x] Middle Acrylic
    - [x] Front Acrylic
- [x] Make the 5 "key switch" holes in the "Back Acrylic"
- [x] Make the 5 "key caps" perforations in
    - [x] Middle Acrylic
    - [x] Front Acrylic
- [x] Drill the 3 Encoders hole in Back Acrylic
- [x] Drill the 3 Knob Encoders hole in
    - [x] Middle Acrylic
    - [x] Front Acrylic
- [x] Drill the Red Momentary Push Button Switch in
    - [x] Back Acrylic
    - [x] Middle Acrylic
    - [x] Front Acrylic
- [x] Generate cuts files
    - [x] 3mm-Black-Microcontroller_Layer.svg
    - [x] 3mm-Black-Microcontroller_Layer.pdf
    - [x] 3mm-Black-Back_Layer.svg
    - [x] 3mm-Black-Back_Layer.pdf
    - [x] 3mm-Translucent-Middle_Layer.svg
    - [x] 3mm-Translucent-Middle_Layer.pdf
    - [x] 2mm-White-Front_Leyer.svg
    - [x] 2mm-White-Front_Leyer.pdf
- [x] Generate PNG image
- [ ] Generating the engraving
      - [ ] Make engrave ditectory
      - [ ] Generate SVG
      - [ ] Generate PDF with vectorized text

Closed 2023-03-12.

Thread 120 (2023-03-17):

Redesign the "Shields and Countermeasures Module" according to SC version 3.18.1

aztlek, 2023-03-17:
## Redesign

- [x] Redesign the "ModulePanel_110mmWidth.svg" template to have the USB connector perforation
- [x] Include the keybinding "Decoy – Panic Launch (tab)"

## Make the holes in

### Front leyer

- [x] Drill the holes for the 4 front bolts
- [x] Make the perforations of the keycaps
- [x] Make the holes of the knobs of the encoders with the new size

### Middle leyer

- [x] Drill the holes for the 4 front bolts
- [x] Make the perforations of the keycaps
- [x] Make the holes of the knobs of the encoders with the new size

### Back leyer

- [x] Drill the holes for the 4 front bolts
- [x] Drill the holes for the 4 back bolts
- [x] Drill the holes for the key switches
- [x] Make the holes for the encoders

### Microcontroller leyer

- [x] Drill the holes for the 4 front bolts
- [x] Drill the holes for the 4 back bolts
- [x] Drill the USB connector

## Generate cuts files

- [x] 3mm-Black-Microcontroller_Layer.svg
- [x] 3mm-Black-Microcontroller_Layer.pdf
- [x] 3mm-Black-Back_Layer.svg
- [x] 3mm-Black-Back_Layer.pdf
- [x] 3mm-Translucent-Middle_Layer.svg
- [x] 3mm-Translucent-Middle_Layer.pdf
- [x] 2mm-White-Front_Leyer.svg
- [ ] 2mm-White-Front_Leyer.pdf

## Update files

- [x] Regenerate module image
- [x] Edit the README.md to put the new image "ShieldsCountermeasuresModule_110mmWidth.png"
- [x] NumberOfKeys_StarCitizen
- [x] Update ComponentInventory
- [x] Include the module in "ModularCockpit_770x120mm.svg"
- [x] Regenerate PNG of "ModularCockpit_770x120mm.png"

##  Generating the engraving

- [x] Generate SVG
- [x] Generate PDF with vectorized text

Closed 2023-04-20.

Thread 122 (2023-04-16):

Redesign "Mining Module"   for USB and encoders

aztlek, 2023-04-16:
## Redesign for USB and encoders

- [x] Change the drill of the encoders with the new size.

## Generate cuts files

- [x] 3mm-Translucent-Middle_Layer.svg
- [x] 3mm-Translucent-Middle_Layer.pdf
- [x] 2mm-White-Front_Leyer.svg
- [x] 2mm-White-Front_Leyer.pdf

Closed 2023-04-17.

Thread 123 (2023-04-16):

Redesign "Radar and Scanning Module"  according to SC version 3.18.1

aztlek, 2023-04-16:
## Design

- [ ] ??

## Redesign for USB and encoders

- [ ] Put the drill for the USB cable.
- [ ] Change the drill of the encoders with the new size.

## Generate cuts files

- [ ] 3mm-Black-Microcontroller_Layer.svg
- [ ] 3mm-Black-Microcontroller_Layer.pdf
- [ ] 3mm-Black-Back_Layer.svg
- [ ] 3mm-Black-Back_Layer.pdf
- [ ] 3mm-Translucent-Middle_Layer.svg
- [ ] 3mm-Translucent-Middle_Layer.pdf
- [ ] 2mm-White-Front_Leyer.svg
- [ ] 2mm-White-Front_Leyer.pdf

## Generate PNG files

- [ ] Regenerate module image
- [ ] Include the module in "ModularCockpit_770x120mm.svg"
- [ ] Regenerate PNG of "ModularCockpit_770x120mm.png"

##  Generating the engraving

- [ ] Make engrave ditectory
- [ ] Generate SVG
- [ ] Generate PDF with vectorized text

Closed 2023-04-17.

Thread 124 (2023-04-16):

Design the "Salvage Module" according to SC version 3.18.1

aztlek, 2023-04-16:
## Design

- [ ] Salvage Mode (Toggle)
- [ ] Salvage Model Gimbal (Toggle)
- [ ] Increase Beam Spacing
- [ ] Decrease Beam Spacing
- [ ] Relative Beam Spacing
- [ ] Absolute Beam Spacing
- [ ] Salvage Beam Axis (Toggle)
- [ ] Cycle Left Salvage Modifiers
- [ ] Cycle Right Salvage Modifiers

## Redesign for USB and encoders

- [ ] Put the drill for the USB cable.
- [ ] Change the drill of the encoders with the new size.

## Generate cuts files

- [ ] 3mm-Black-Microcontroller_Layer.svg
- [ ] 3mm-Black-Microcontroller_Layer.pdf
- [ ] 3mm-Black-Back_Layer.svg
- [ ] 3mm-Black-Back_Layer.pdf
- [ ] 3mm-Translucent-Middle_Layer.svg
- [ ] 3mm-Translucent-Middle_Layer.pdf
- [ ] 2mm-White-Front_Leyer.svg
- [ ] 2mm-White-Front_Leyer.pdf

## Generate PNG files

- [ ] Regenerate module image
- [ ] Include the module in "ModularCockpit_770x120mm.svg"
- [ ] Regenerate PNG of "ModularCockpit_770x120mm.png"

##  Generating the engraving

- [ ] Make engrave ditectory
- [ ] Generate SVG
- [ ] Generate PDF with vectorized text

Closed 2023-05-03.

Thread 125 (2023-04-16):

Design the "Turret Module" for USB drill and new encoder drill

aztlek, 2023-04-16:
## Redesign for USB and encoders

- [x] Put the drill for the USB cable.
- [x] Change the drill of the encoders with the new size.

## Generate cuts files

- [x] 3mm-Black-Microcontroller_Layer.svg
- [x] 3mm-Black-Microcontroller_Layer.pdf
- [x] 3mm-Translucent-Middle_Layer.svg
- [x] 3mm-Translucent-Middle_Layer.pdf
- [x] 2mm-White-Front_Leyer.svg
- [x] 2mm-White-Front_Leyer.pdf

Closed 2023-04-18.

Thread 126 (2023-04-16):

Redesign the "Weapons Module" according to SC version 3.18.1

aztlek, 2023-04-16:
## Redesing

- [ ] Cycle Fixed / Auto Gimbal Modes
- [ ] Set Fixed Gimba Mode (Long Press)
- [ ] Set Auto Gimbal Mode (Long Press)
- [ ] Set Manual Gimbal Mode (Long Press)
- [ ] Set Fixed Gombal Mode (Short Press)
- [ ] Set Auto Gimbal Mode (short Press)
- [ ] Set Manual Gimbal Mode (Short Press)
- [ ] Toggle Lead / Lag PIPs
- [ ] Set Lags PIPs
- [ ] Set Lead PIPs

## Redesign for USB and encoders

- [ ] Put the drill for the USB cable.
- [ ] Change the drill of the encoders with the new size.

## Generate cuts files

- [ ] 3mm-Black-Microcontroller_Layer.svg
- [ ] 3mm-Black-Microcontroller_Layer.pdf
- [ ] 3mm-Black-Back_Layer.svg
- [ ] 3mm-Black-Back_Layer.pdf
- [ ] 3mm-Translucent-Middle_Layer.svg
- [ ] 3mm-Translucent-Middle_Layer.pdf
- [ ] 2mm-White-Front_Leyer.svg
- [ ] 2mm-White-Front_Leyer.pdf

## Generate PNG files

- [ ] Regenerate module image
- [ ] Include the module in "ModularCockpit_770x120mm.svg"
- [ ] Regenerate PNG of "ModularCockpit_770x120mm.png"

##  Generating the engraving

- [ ] Make engrave ditectory
- [ ] Generate SVG
- [ ] Generate PDF with vectorized text

Closed 2023-05-03.

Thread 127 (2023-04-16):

Redesign the "Shields and Countermeasures Module" according to SC version 3.18.1

aztlek, 2023-04-16:
## Relocate:

- [ ] "Decoy" label text.
- [ ] "Launch Burst" button. And drills.
- [ ] "Raise Level" text to the right of the shields

## Design:

- [ ] Decoy – Panic Launch (tab).
- [ ] Update the NumberOfKeys_StarCitizen.ods spreadsheet.

## Drill for "Decoy – Panic Launch" in:

- [ ] Front Layer
- [ ] Middle Reader
- [ ] Back Read

## Design for USB and encoders

- [ ] Put the drill for the USB cable.
- [ ] Change the drill of the encoders with the new size.

## Generate cuts files

- [ ] 3mm-Black-Microcontroller_Layer.svg
- [ ] 3mm-Black-Microcontroller_Layer.pdf
- [ ] 3mm-Black-Back_Layer.svg
- [ ] 3mm-Black-Back_Layer.pdf
- [ ] 3mm-Translucent-Middle_Layer.svg
- [ ] 3mm-Translucent-Middle_Layer.pdf
- [ ] 2mm-White-Front_Leyer.svg
- [ ] 2mm-White-Front_Leyer.pdf

## Generate PNG files

- [ ] Regenerate module image
- [ ] Include the module in "ModularCockpit_770x120mm.svg"
- [ ] Regenerate PNG of "ModularCockpit_770x120mm.png"

##  Generating the engraving

- [ ] Make engrave ditectory
- [ ] Generate SVG
- [ ] Generate PDF with vectorized text

Closed 2023-04-28.

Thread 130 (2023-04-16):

Design the "Social Module"

aztlek, 2023-04-16:
## Social - General:
- [ ] Re-spawn
- [ ] Exit seat
- [ ] CommLink App (toggle)
- [ ] Chat Window (toggle)
- [ ] Chat Window Focus

## Social - Invites
- [ ] Accept Invite
- [ ] Reject Invite
- [ ] Ignore Invite (Hold)
- [ ] Chat Window Focus.

## Design for USB and encoders

- [ ] Put the drill for the USB cable.
- [ ] Change the drill of the encoders with the new size.

## Generate cuts files

- [ ] 3mm-Black-Microcontroller_Layer.svg
- [ ] 3mm-Black-Microcontroller_Layer.pdf
- [ ] 3mm-Black-Back_Layer.svg
- [ ] 3mm-Black-Back_Layer.pdf
- [ ] 3mm-Translucent-Middle_Layer.svg
- [ ] 3mm-Translucent-Middle_Layer.pdf
- [ ] 2mm-White-Front_Leyer.svg
- [ ] 2mm-White-Front_Leyer.pdf

## Generate PNG files

- [ ] Regenerate module image
- [ ] Include the module in "ModularCockpit_770x120mm.svg"
- [ ] Regenerate PNG of "ModularCockpit_770x120mm.png"

##  Generating the engraving

- [ ] Make engrave ditectory
- [ ] Generate SVG
- [ ] Generate PDF with vectorized text

Closed 2023-04-28.

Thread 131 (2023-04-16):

Redesign the "Emotes Module" to 32 keys

aztlek, 2023-04-16:
## Redesign

- [ ] 32 keys.

## Redesign for USB and encoders

- [ ] Put the drill for the USB cable.
- [ ] Change the drill of the encoders with the new size.

## Generate cuts files

- [ ] 3mm-Black-Microcontroller_Layer.svg
- [ ] 3mm-Black-Microcontroller_Layer.pdf
- [ ] 3mm-Black-Back_Layer.svg
- [ ] 3mm-Black-Back_Layer.pdf
- [ ] 3mm-Translucent-Middle_Layer.svg
- [ ] 3mm-Translucent-Middle_Layer.pdf
- [ ] 2mm-White-Front_Leyer.svg
- [ ] 2mm-White-Front_Leyer.pdf

## Generate PNG files

- [ ] Regenerate module image
- [ ] Include the module in "ModularCockpit_770x120mm.svg"
- [ ] Regenerate PNG of "ModularCockpit_770x120mm.png"

##  Generating the engraving

- [ ] Make engrave ditectory
- [ ] Generate SVG
- [ ] Generate PDF with vectorized text

Closed 2023-04-18.

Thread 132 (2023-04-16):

Redesign the "Movement Module" according to SC version 3.18.1

aztlek, 2023-04-16:
## Redesign to include

- [ ] Swap Yaw / Roll (Toggle)
- [ ] Cycle mouse mode (Vjoy / Relative)
- [ ] @ui+v_ifcs_esp_hold

## Redesign for USB and encoders

- [ ] Put the drill for the USB cable.
- [ ] Change the drill of the encoders with the new size.

## Generate cuts files

- [ ] 3mm-Black-Microcontroller_Layer.svg
- [ ] 3mm-Black-Microcontroller_Layer.pdf
- [ ] 3mm-Black-Back_Layer.svg
- [ ] 3mm-Black-Back_Layer.pdf
- [ ] 3mm-Translucent-Middle_Layer.svg
- [ ] 3mm-Translucent-Middle_Layer.pdf
- [ ] 2mm-White-Front_Leyer.svg
- [ ] 2mm-White-Front_Leyer.pdf

## Generate PNG files

- [ ] Regenerate module image
- [ ] Include the module in "ModularCockpit_770x120mm.svg"
- [ ] Regenerate PNG of "ModularCockpit_770x120mm.png"

##  Generating the engraving

- [ ] Make engrave ditectory
- [ ] Generate SVG
- [ ] Generate PDF with vectorized text

Closed 2023-05-02.

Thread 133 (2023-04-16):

Redesign the "Radar and Scanning Module" according to SC version 3.18.1

aztlek, 2023-04-16:
## Relocate:

- [x] "Active Ping" button to the right, to make room for Tagging.
- [x] "Ping Angle" Encoder

## Clear and redo the "Tagging" Button drills in:

- [x] Front Layer
- [x] Middle Reader
- [x] Back Read

## Clear and redo the "Active Ping" Button drills in:

- [x] Front Layer
- [x] Middle Reader
- [x] Back Read

## Delete and redo the "Ping Angle" Encoder drills in:

- [x] Front Layer
- [x] Middle Reader
- [x] Back Read

## Clear and redo "Front Bolts" in:

- [x] Front Layer
- [x] Middle Reader
- [x] Back Read

## Redesign to include

- [x]  Add: @ui_CIRadartTagging

## Redesign for  encoders

- [x] Change the drill of the encoders with the new size.

## Generate cuts files

- [x] 3mm-Black-Back_Layer.svg
- [x] 3mm-Black-Back_Layer.pdf
- [x] 3mm-Translucent-Middle_Layer.svg
- [x] 3mm-Translucent-Middle_Layer.pdf
- [x] 2mm-White-Front_Leyer.svg
- [x] 2mm-White-Front_Leyer.pdf

## Generate PNG files

- [x] Regenerate module image
- [x] Include the module in "ModularCockpit_770x120mm.svg"
- [x] Regenerate PNG of "ModularCockpit_770x120mm.png"

##  Generating the engraving

- [x] Make engrave ditectory
- [x] Generate SVG
- [x] Generate PDF with vectorized text

Closed 2023-04-18.

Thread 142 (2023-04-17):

[Power Module] Document connections to Teensy

aztlek, 2023-04-17:
Document the connections to the Teensy with a table that has: Component, component pins, diode orientation and Teensy pin.

Example:

| Component                 | Component Pins | Diode Orientation | Teensy pin |
| ----------------------------- | ----------------------- | :---------------------: | ------------: |
|  Power Toggle Switch  |  1                         |            ->\|\-          |               2 |
|                                      |  2                         |                             |               3 |
|  Shields Toggle Switch |  1                         |            ->\|\-          |               3 |
|                                      |  2                         |                             |               4 |

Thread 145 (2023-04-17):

Redesign the "Missile Module" for USB and encoders

aztlek, 2023-04-17:
Redesign the "Missile Module" for USB and encoders

- [ ] Put the drill for the USB cable.
- [ ] Change the drill of the encoders with the new size.

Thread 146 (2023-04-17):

Redesign the "Cockpit Module" for encoders

aztlek, 2023-04-17:
Redesign the "Cockpit Module" for  encoders:
- [x] Change the drill of the encoders with the new size.

## Generate cuts files

- [x] 3mm-Translucent-Middle_Layer.svg
- [x] 3mm-Translucent-Middle_Layer.pdf
- [x] 2mm-White-Front_Leyer.svg
- [x] 2mm-White-Front_Leyer.pdf

Closed 2023-04-18.

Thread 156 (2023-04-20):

Redesign the module panel templates to have the USB connector perforation

aztlek, 2023-04-20:
- [x] ModulePanel_100mmWidth.svg
- [ ] ModulePanel_110mmWidth.svg
- [ ] ModulePanel_120mmWidth.svg
- [ ] ModulePanel_125mmWidth.svg
- [ ] ModulePanel_150mmWidth.svg
- [ ] ModulePanel_155mmWidth.svg
- [ ] ModulePanel_180mmWidth.svg
- [ ] ModulePanel_50mmWidth.svg
- [ ] ModulePanel_60mmWidth.svg
- [ ] ModulePanel_70mmWidth.svg
- [ ] ModulePanel_80mmWidth.svg
- [ ] ModulePanel_85mmWidth.svg
- [ ] ModulePanel_90mmWidth.svg

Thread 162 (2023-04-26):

[Docking and Landing Module] Put the perforations of the missing front bolds in the back layer

aztlek, 2023-04-26:

Closed 2023-04-28.

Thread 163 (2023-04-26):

[Cockpit Module] Redesign the front and middle layers to fit the key switch and cap cover guard

aztlek, 2023-04-26:

Closed 2023-04-27.

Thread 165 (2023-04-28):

[Power Module] Redesign the module to have the hole for the USB cable in the microcontroller layer

aztlek, 2023-04-28:

Closed 2023-04-28.

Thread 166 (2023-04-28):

[Cockpit Module] Redesign the module to have the hole for the USB cable in the microcontroller layer

aztlek, 2023-04-28:

Closed 2023-04-28.

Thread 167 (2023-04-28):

[Docking and Landing Module] Redesign the module to have the hole for the USB cable in the microcontroller layer

aztlek, 2023-04-28:

Closed 2023-04-28.

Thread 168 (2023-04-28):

[Emotes Module] Redesign the module to have the hole for the USB cable in the microcontroller layer

aztlek, 2023-04-28:

Closed 2023-04-28.

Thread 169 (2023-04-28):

[HUD Module] Redesign the module to have the hole for the USB cable in the microcontroller layer

aztlek, 2023-04-28:

Closed 2023-04-28.

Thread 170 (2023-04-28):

[Mining Module] Redesign the module to have the hole for the USB cable in the microcontroller layer

aztlek, 2023-04-28:

Closed 2023-04-28.

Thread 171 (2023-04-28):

[Missile Module] Redesign the module to have the hole for the USB cable in the microcontroller layer

aztlek, 2023-04-28:

Closed 2023-04-28.

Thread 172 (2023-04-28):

[Power Module] Redesign the module to have the hole for the USB cable in the microcontroller layer

aztlek, 2023-04-28:

Closed 2023-04-28.

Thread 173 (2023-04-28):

[Radar and Scanning] Redesign the module to have the hole for the USB cable in the microcontroller layer

aztlek, 2023-04-28:

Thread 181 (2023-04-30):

[Mining Module] Redesign the "Mining Module" so that the encoder is more separated

aztlek, 2023-04-30:

Closed 2023-05-01.

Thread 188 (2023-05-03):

[Weapons Module] Make the holes of the "Weapons Module

aztlek, 2023-05-03:
- [ ]

## Generate cuts files

- [ ] 3mm-Black-Microcontroller_Layer.svg
- [ ] 3mm-Black-Microcontroller_Layer.pdf
- [ ] 3mm-Black-Back_Layer.svg
- [ ] 3mm-Black-Back_Layer.pdf
- [ ] 3mm-Translucent-Middle_Layer.svg
- [ ] 3mm-Translucent-Middle_Layer.pdf
- [ ] 2mm-White-Front_Leyer.svg
- [ ] 2mm-White-Front_Leyer.pdf

## Generate PNG files

- [ ] Regenerate module image
- [ ] Include the module in "ModularCockpit_770x120mm.svg"
- [ ] Regenerate PNG of "ModularCockpit_770x120mm.png"

##  Generating the engraving

- [ ] Make engrave ditectory
- [ ] Generate SVG
- [ ] Generate PDF with vectorized text

Closed 2023-07-24.

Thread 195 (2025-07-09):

Implement pseudohub as the firmware of the "Central Control Panel Panel"

aztlek, 2025-07-09:
Multiple Teensy joysticks can be connected to the pseudohub, and it unifies them into a single one so that the operating system only sees one joystick. This is done through a USB hub connected to a Teensy 4.1 via the "USB Host" port.

In this issue, you must develop the firmware for the pseudohub that will be connected to the Central Control Panel.

Closed 2025-07-09.

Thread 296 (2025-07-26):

Add missing items to the bill of materials

aztlek, 2025-07-26:
| Material                                                                                                                                  | Qty. | Links                                                                           |
| ----------------------------------------------------------------------------------------------------------------------------------------- | ---: | ------------------------------------------------------------------------------- |
| Teensy 4.0                                                                                                                                |    1 | [Amz](https://www.amazon.com/dp/B07W5J3WNH)                                     |
| Terminal Block Breakout Board Module for Teensy 4.0, Screw Mount Version                                                                  |    1 | [Amz](https://www.amazon.com/dp/B08R7PVCFN)                                     |
| Female to Female Thread Spacer Screws Brass Hex Standoff M3 x 60mm                                                                        |    4 | [Amz](https://www.amazon.com/dp/B09V272N1N)                                     |
| 3Mx6 Socket Head Cap Bolts                                                                                                                |    4 | 1 package[Amz](https://www.amazon.com/dp/B00W8YSCIS)                            |
| 3M Flat Washers                                                                                                                           |    8 | In one package [Amz](https://www.amazon.com/dp/B08CHHLQQS)                      |
| 3Mx12 Button Head Socket Cap Bolts                                                                                                        |    2 | In one package [Amz](https://www.amazon.com/dp/B08CHHLQQS)                      |
| 3Mx5 Button Head Socket Cap Bolts                                                                                                         |    4 | In one package [Amz](https://www.amazon.com/dp/B08CHHLQQS)                      |
| Plastic Primer                                                                                                                            |    1 | [mtn](https://www.montanacolors.com/en/productos/mtn-pro-plastic-primer-spray/) |
| Black Matte Paint R-9011                                                                                                                  |    1 | [mtn](https://www.montanacolors.com/en/productos/mtn-94-aerosol-spray-paint/)   |
| 2mm white acrylic                                                                                                                         |    1 |                                                                                 |
| 3mm translucent acrylic                                                                                                                   |    1 |                                                                                 |
| 3mm black acrylic                                                                                                                         |    1 |                                                                                 |
| 3mm black acrylic                                                                                                                         |    1 |                                                                                 |

- [x] CameraModule
- [x] CockpitModule
- [x] DockingLandingModule
- [x] EmotesModule
- [x] HudModule
- [x] MiningModule
- [x] MissilesModule
- [x] MovementModule
- [x] PowerModule
- [x] RadarScanningModule
- [x] SalvageModule
- [x] ShieldsCountermeasuresModule
- [x] SocialModule
- [x] StopwatchModule
- [x] TargetCyclingModule
- [x] TargetingModule
- [x] TorretModule
- [x] WeaponsModule

Closed 2025-07-28.

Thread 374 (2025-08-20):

Design the front view and drill of the "Panel Mount DC Power Barrel Jack Plug Connector"

aztlek, 2025-08-20:
Some measures in [Panel Mount DC Power Barrel Jack Plug Connector](https://www.amazon.com/dp/B0B66T1QJZ)

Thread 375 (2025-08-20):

Design the front view and drill of "QIANRENON Micro USB Threaded Fixed Mount Charging Short Cable Adapter Micro USB Male to Female"

aztlek, 2025-08-20:
The measures in [QIANRENON Micro USB Threaded Fixed Mount Charging Short Cable Adapter Micro USB Male to Female](https://www.amazon.com/-/es/dp/B0D17N33TX)

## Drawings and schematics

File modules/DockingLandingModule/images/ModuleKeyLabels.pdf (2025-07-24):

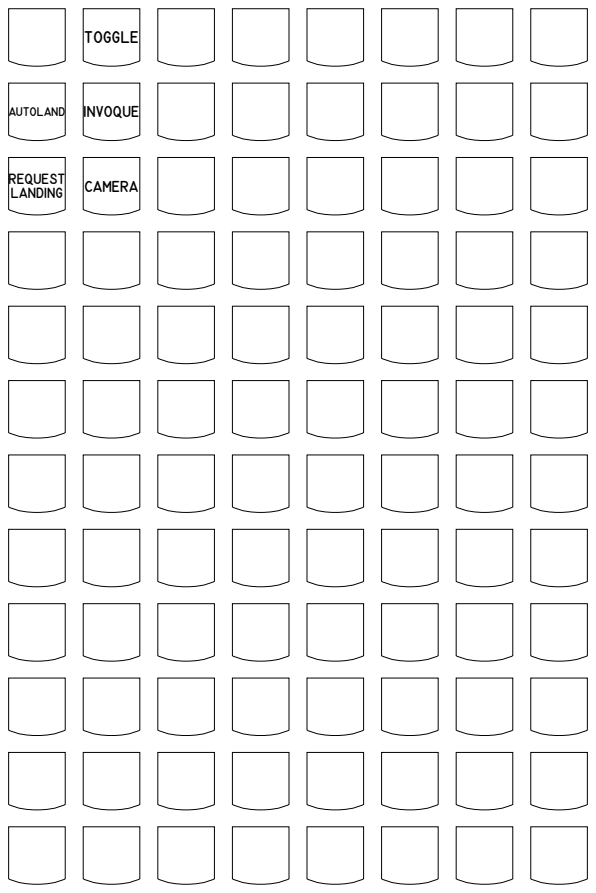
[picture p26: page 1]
CAMERA; INVOQUE; TOGGLE; Request Landing; Autoland

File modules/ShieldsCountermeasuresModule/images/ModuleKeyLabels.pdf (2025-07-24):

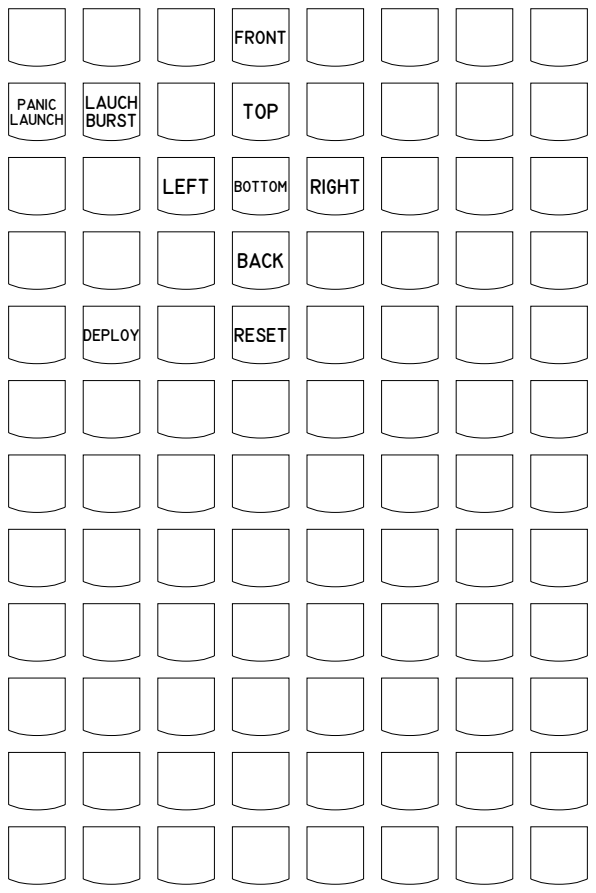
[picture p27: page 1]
front; TOP; LEFT; BOTTOM; RIGHT; BACK; reset; Lauch Burst; Panic Launch; Deploy

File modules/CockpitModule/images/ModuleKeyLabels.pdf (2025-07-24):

# exit seat

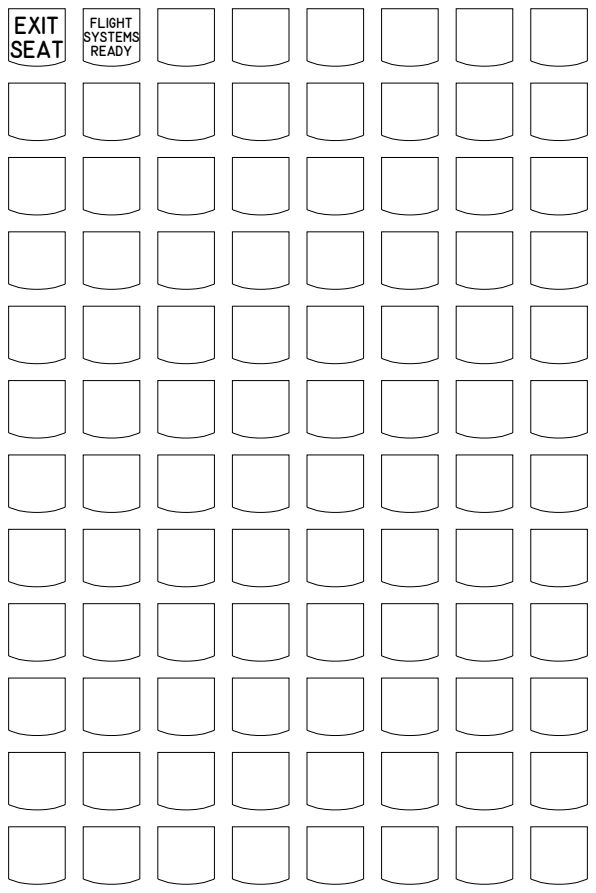
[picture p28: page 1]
Flight Systems Ready

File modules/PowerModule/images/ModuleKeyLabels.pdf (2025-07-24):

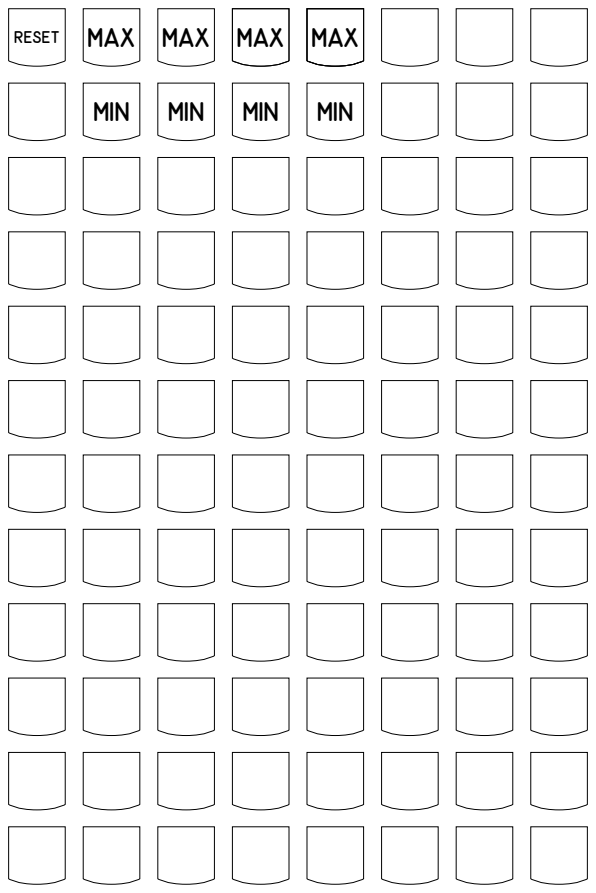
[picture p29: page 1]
RESET; MAX; MIN

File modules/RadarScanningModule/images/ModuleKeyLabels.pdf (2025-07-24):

## ACTIVE PING

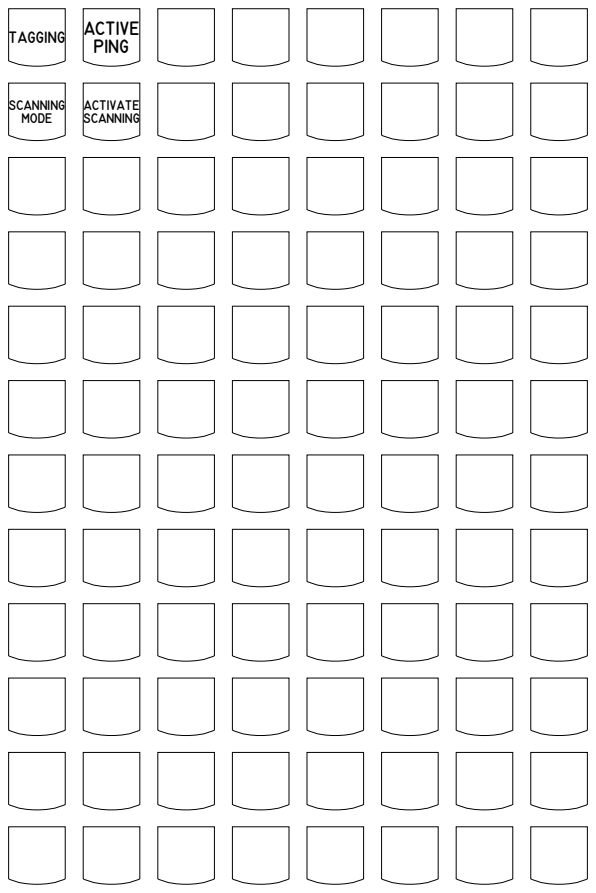
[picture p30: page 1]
Activate Scanning; Scanning Mode; TAGGING

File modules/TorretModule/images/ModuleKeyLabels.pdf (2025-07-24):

### Vjoy FPS

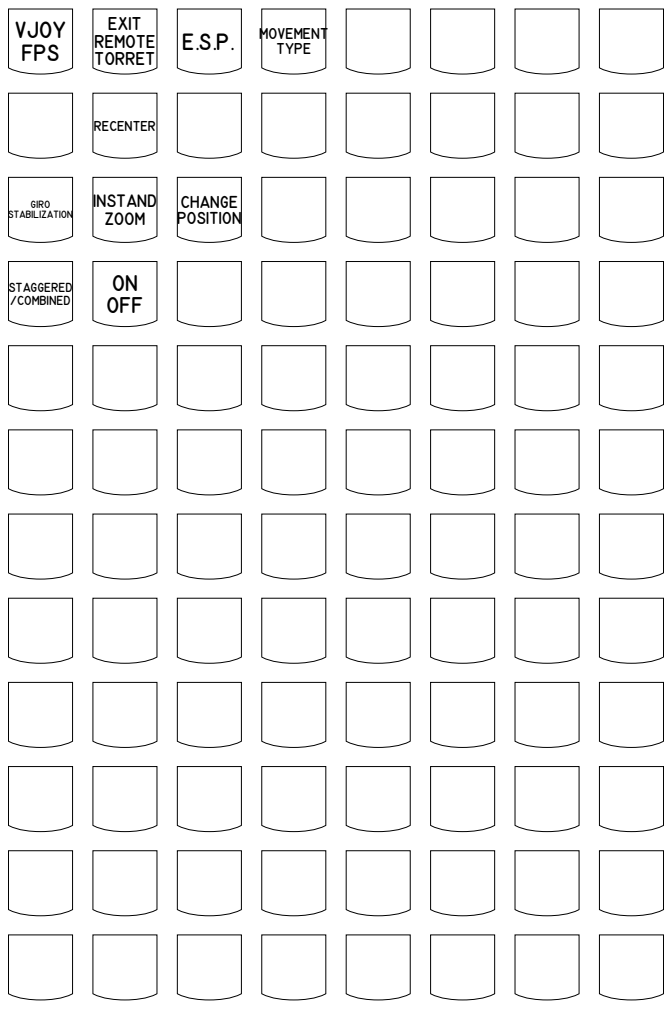
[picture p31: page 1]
EXIT REMOTE TORRET; RECENTER; GIRO STABILIZATION; ON OFF; INSTAND ZOOM; MOVEMENT TYPE; staggered /combined; CHANGE POSITION

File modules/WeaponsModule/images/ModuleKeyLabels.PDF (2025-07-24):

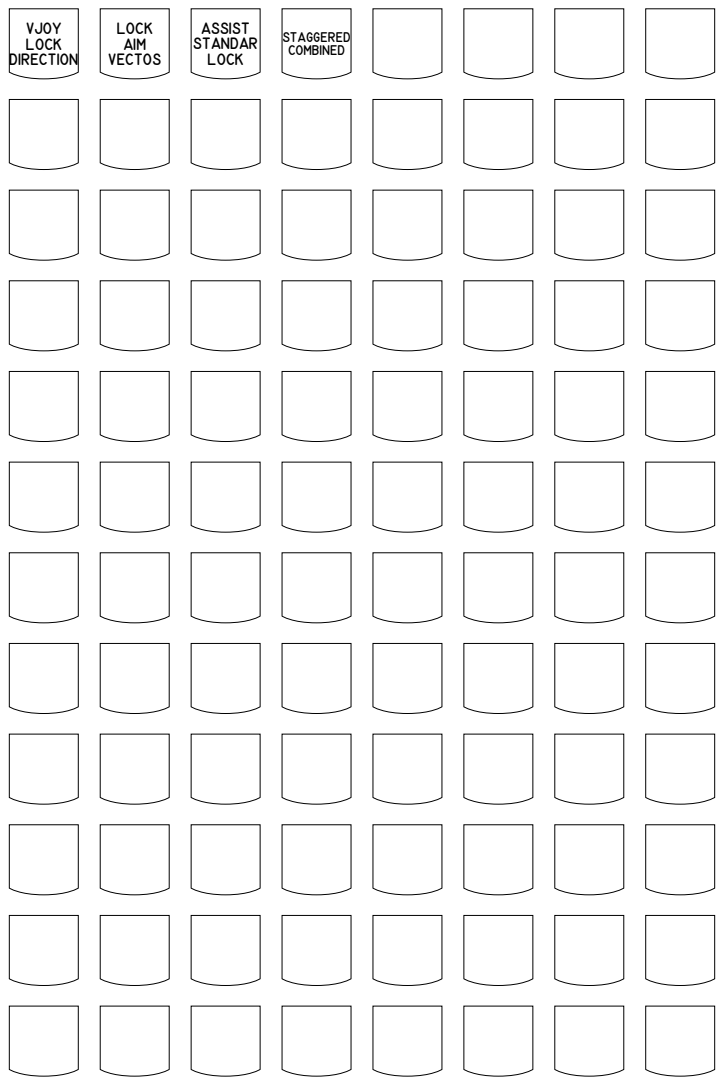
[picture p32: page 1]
VJOY LOCK DIRECTION; LOCK AIM VECTOS; ASSIST STANDAR LOCK; STAGGERED COMBINED

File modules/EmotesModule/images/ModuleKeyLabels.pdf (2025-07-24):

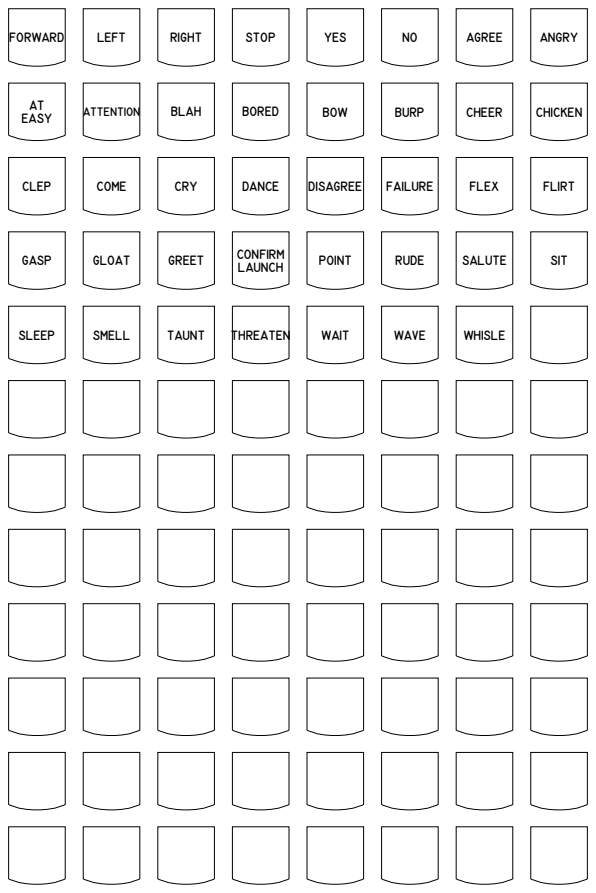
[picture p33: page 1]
Forward; Left; Right; Stop; Yes; Agree; Angry; Easy; Attention; Blah; Bored; Bow; Burp; Cheer; Chicken; Clep; Come; Cry; Dance; Disagree; Failure; Flex; Flirt; Gasp; Gloat; Greet; Confirm; Launch; Point; Rude; Salute; Sit; Sleep; Smell; Taunt; Threaten; Wait; Wave; Whisle

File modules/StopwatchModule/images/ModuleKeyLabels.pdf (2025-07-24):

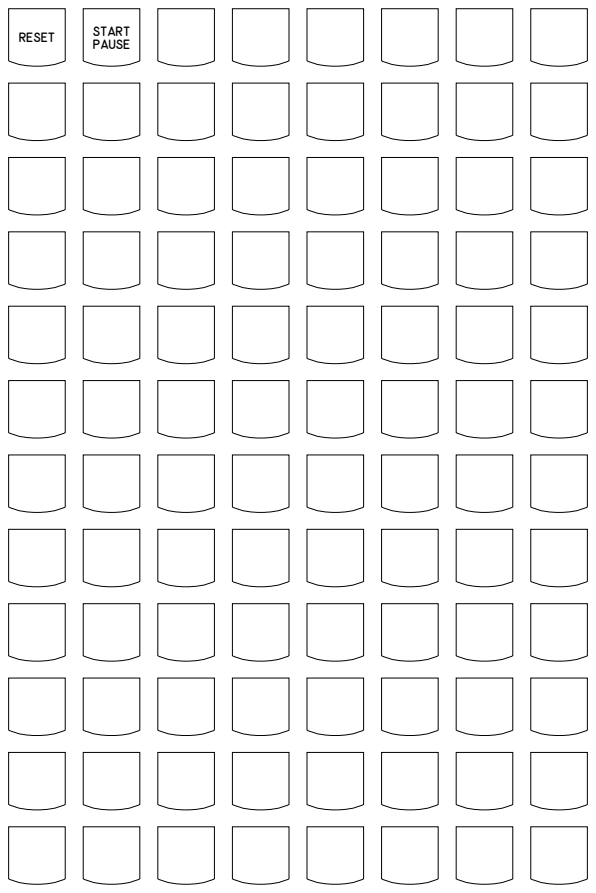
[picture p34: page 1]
RESET; STARt; PAUSE

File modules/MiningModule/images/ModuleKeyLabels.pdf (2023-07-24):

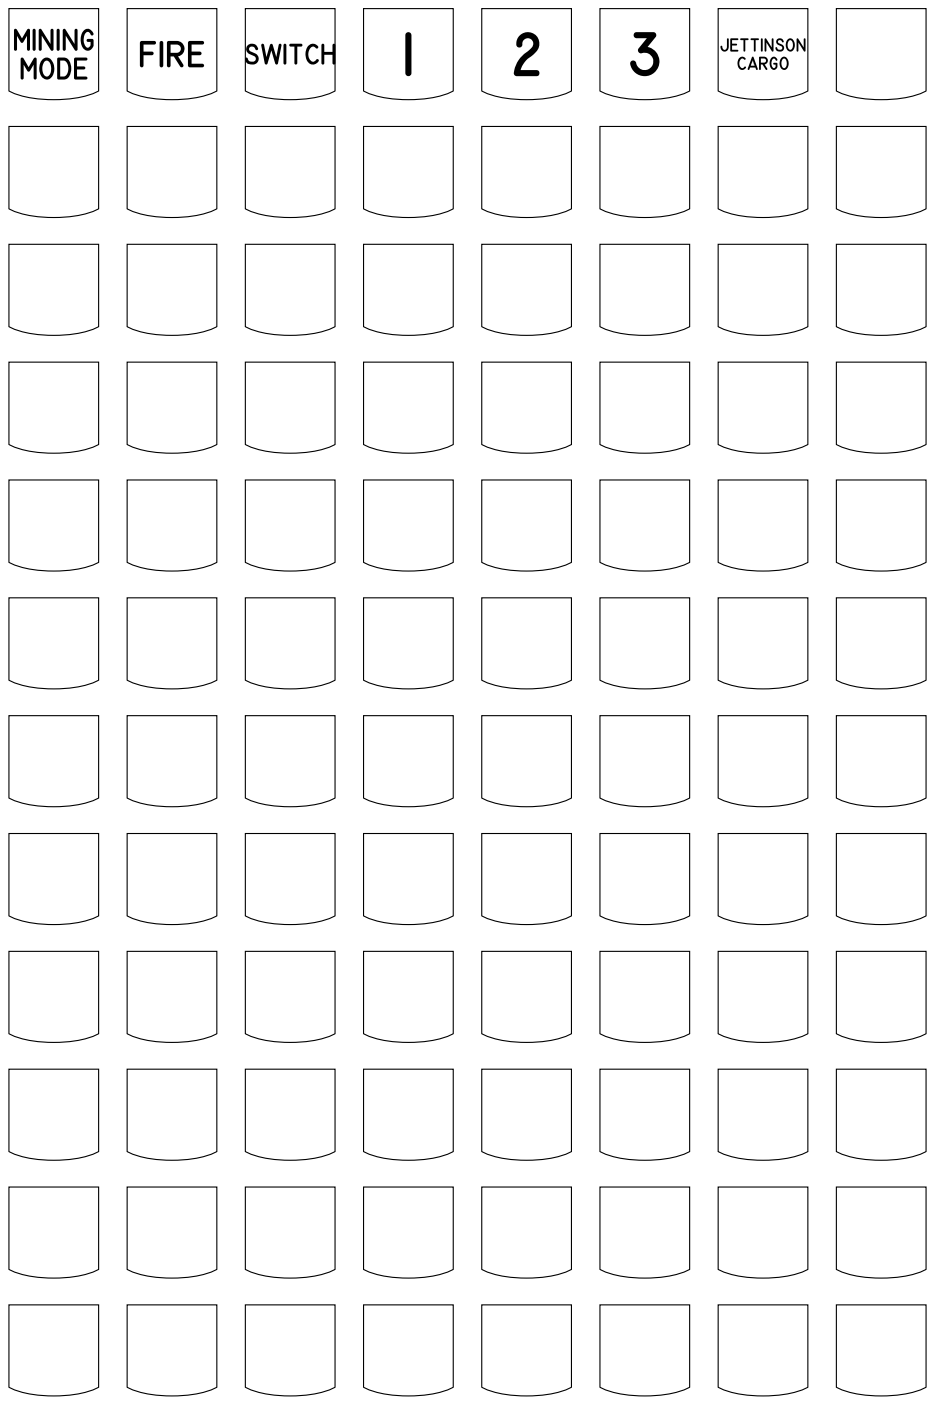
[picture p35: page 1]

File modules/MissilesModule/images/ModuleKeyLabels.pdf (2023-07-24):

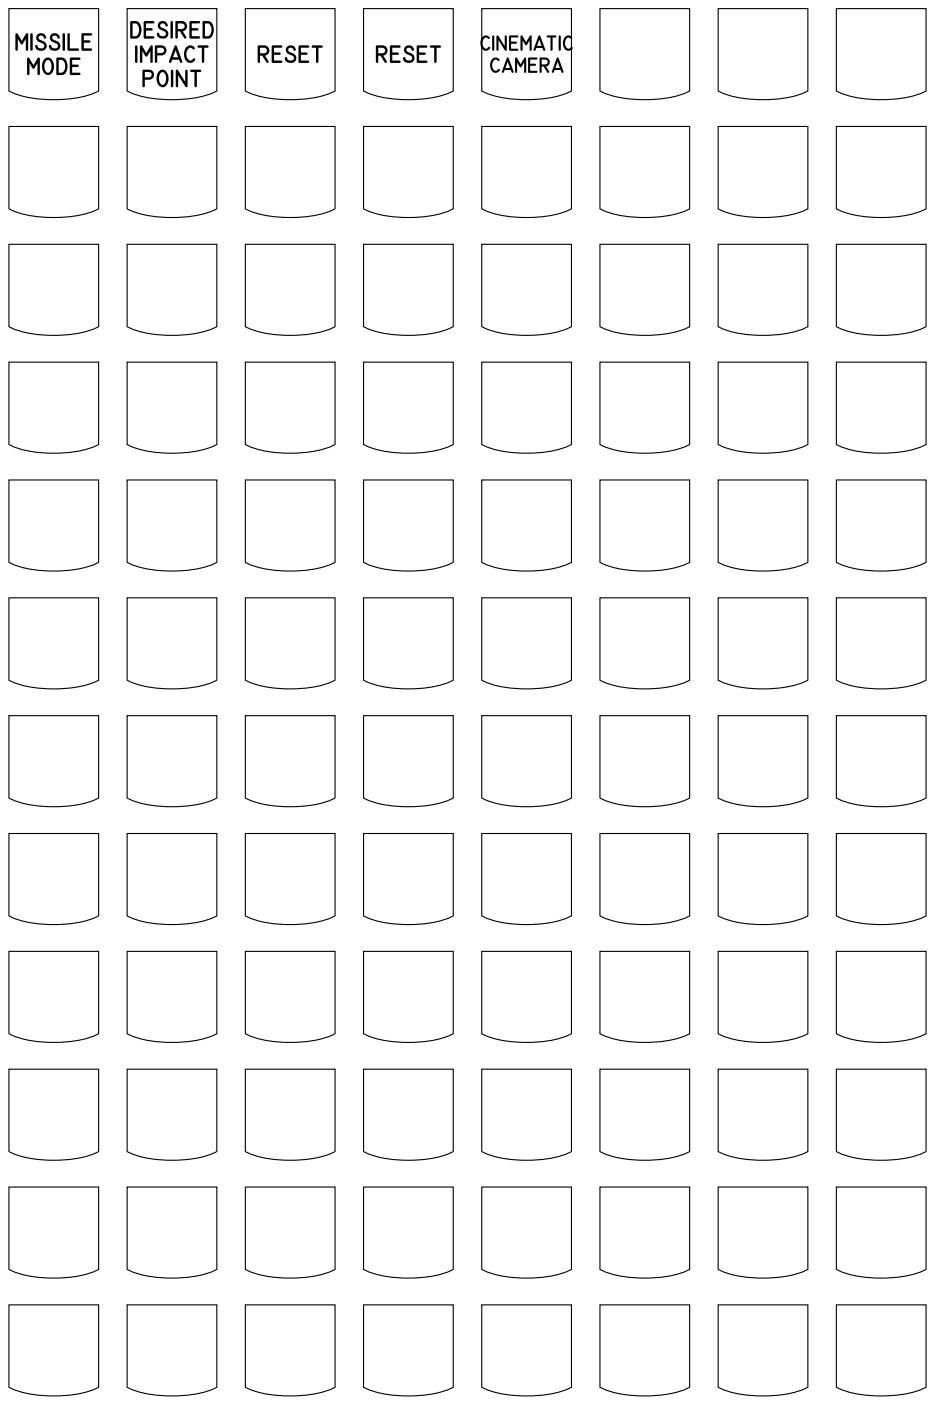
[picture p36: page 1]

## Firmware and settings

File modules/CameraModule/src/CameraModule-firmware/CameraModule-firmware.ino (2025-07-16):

/*
||
|| @file firmware.ino
|| @author Luis Alejandro Bernal Romero (Aztlek)
|| @description
|| | This firmware is for the "Camera Module" of the "Modular Cockpit".
|| | @see Power Module: https://github.com/aztlek/ModularCockpit/tree/main/modules/CameraModule
|| | @see Modular Cockpit: https://github.com/aztlek/ModularCockpit.
|| #
|| 
|| @license
|| | Copyright (C) 2020 Luis Alejandro Bernal Romero (Aztlek)
|| | 
|| | This program is free software: you can redistribute it and/or modify
|| | it under the terms of the GNU General Public License as published by
|| | the Free Software Foundation, either version 3 of the License, or
|| | (at your option) any later version.
|| | 
|| | This program is distributed in the hope that it will be useful,
|| | but WITHOUT ANY WARRANTY; without even the implied warranty of
|| | MERCHANTABILITY or FITNESS FOR A PARTICULAR PURPOSE.  See the
|| | GNU General Public License for more details.
|| | 
|| | You should have received a copy of the GNU General Public License
|| | along with this program.  If not, see <http://www.gnu.org/licenses/>.
|| #
||
*/
 
#include <Keypad.h>
#include <Encoder.h>

// #define DEBUG

// Keypad
const byte NUMROWS = 4;
const byte NUMCOLS = 5;
const byte MAXKEYS = NUMROWS * NUMCOLS;
char keys[NUMROWS][NUMCOLS] = {
  { 0,  1,  2,  3,  4},
  { 5,  6,  7,  8,  9},
  {10, 11, 12, 13, 14},
  {15, 16, 17, 18, 19}
};


// Characters
int chs[MAXKEYS] = {
  'z'     , KEY_F4  , 'z'     , 0             , 0     ,
  KEYPAD_7, KEYPAD_8, KEYPAD_9, KEYPAD_ASTERIX, 1     ,
  KEYPAD_4, KEYPAD_5, KEYPAD_6, 0             , 2     ,
  KEYPAD_1, KEYPAD_2, KEYPAD_3, 0             , KEY_F4
};

#define keyToCh(key) (chs[key])

byte rowPins[NUMROWS] = {  2,  3,  4,  5};
byte colPins[NUMCOLS] = {  6,  7,  8,  9, 10};

Keypad kpd = Keypad( makeKeymap(keys), rowPins, colPins, NUMROWS, NUMCOLS );

// Keys
#define KEY_PRESS_TIME 150

// Encoders
#define NUM_ENCODERS 6
Encoder encoders[NUM_ENCODERS] = {
  Encoder(11, 12), // 0 ZOOM_3RD_PERSON
  Encoder(22, 21), // 1 FOV
  Encoder(20, 19), // 2 Y_OFFSET
  Encoder(18, 17), // 3 Z_OFFSET
  Encoder(16, 15), // 4 DOF
  Encoder(14, 29)  // 5 X_OFFSET
};
//                               ZOOM_3RD_PERSON, FOV         , Y_OFFSET, Z_OFFSET     , DOF     , X_OFFSET
int inc_encoder[NUM_ENCODERS] = {  1            , KEYPAD_PLUS , KEY_UP  , KEY_PAGE_UP  , KEY_HOME, KEY_RIGHT};
int dec_encoder[NUM_ENCODERS] = { -1            , KEYPAD_MINUS, KEY_DOWN, KEY_PAGE_DOWN, KEY_END , KEY_LEFT} ;
long oldPositionEncoders[NUM_ENCODERS] = { 0, 0, 0, 0, 0, 0};
long newPositionEncoders[NUM_ENCODERS];
#define ENCODER_INCREMENT_KEYS 1


// ====== Potentiometers ======

#define NUM_POTENTIOMETERS 1
byte potentiometersPins[NUM_POTENTIOMETERS] =
{
  41
};

int potentiometersOldValues[NUM_POTENTIOMETERS] = {
  0
};
int potentiometersValues[NUM_POTENTIOMETERS] = {
  0
};

const int potentiometerDelta = 8;

// ===========================

String msg;

const int ledPin = 13;

extern "C" uint32_t set_arm_clock(uint32_t frequency);

void setup() {
  set_arm_clock(24000000);

#ifdef DEBUG
  Serial.begin(9600);
#endif

  // Led as power indicator
  temporarily_increase_led_brightness(1000);
  
  // Encoders
  pinMode(11, INPUT_PULLUP);
  pinMode(12, INPUT_PULLUP);
  pinMode(22, INPUT_PULLUP);
  pinMode(21, INPUT_PULLUP);
  pinMode(20, INPUT_PULLUP);
  pinMode(19, INPUT_PULLUP);
  pinMode(18, INPUT_PULLUP);
  pinMode(17, INPUT_PULLUP);
  pinMode(16, INPUT_PULLUP);
  pinMode(15, INPUT_PULLUP);
  pinMode(14, INPUT_PULLUP);
  pinMode(29, INPUT_PULLUP);


  
  // ====== Potentiometers ======

  for(unsigned i = 0; i < NUM_POTENTIOMETERS; i++) {
    potentiometersValues[i] = analogRead(potentiometersPins[i]);
    potentiometersOldValues[i] = potentiometersValues[i];
  }

#ifdef DEBUG
  Serial.begin(9600);
#endif
}


void loop() {

    // Fills kpd.key[ ] array with up-to 10 active keys.
    // Returns true if there are ANY active keys.
    if (kpd.getKeys())
    {
        for (int i=0; i < LIST_MAX; i++)   // Scan the whole key list.
        {
            if ( kpd.key[i].stateChanged )   // Only find keys that have changed state.
            {
              byte code = (byte)kpd.key[i].kchar;
              int ch = keyToCh(code);
              KeyState keyState = kpd.key[i].kstate;
              switch (keyState) {  // Report active key state : IDLE, PRESSED, HOLD, or RELEASED
                case PRESSED:
                  msg = "PRESSED";
                  if(code == 9 || code == 14) {
                      Joystick.button((uint8_t)ch, 1);
                  }
                  else if(ch != 0) {
                    Keyboard.press(ch);
                  }                    
                break;
                case RELEASED:
                  msg = "RELEASED";
                  if(code == 9 || code == 14) {
                      Joystick.button((uint8_t)ch, 0);
                  }
                  else if(ch != 0) {
                    Keyboard.release(ch);
                  }
                break;
                default:
                break;
              }    
#ifdef DEBUG
              Serial.printf("kpd.key[%d]: Code=%d ,Ch=", i, code);
              switch(ch) {
                case KEYPAD_7: Serial.print("KEYPAD_7"); break;
                case KEYPAD_8: Serial.print("KEYPAD_8"); break;
                case KEYPAD_9: Serial.print("KEYPAD_9"); break;
                case KEYPAD_4: Serial.print("KEYPAD_4"); break;
                case KEYPAD_5: Serial.print("KEYPAD_5"); break;
                case KEYPAD_6: Serial.print("KEYPAD_6"); break;
                case KEYPAD_1: Serial.print("KEYPAD_1"); break;
                case KEYPAD_2: Serial.print("KEYPAD_2"); break;
                case KEYPAD_3: Serial.print("KEYPAD_3"); break;
                case KEYPAD_ASTERIX: Serial.print("KEYPAD_ASTERIX"); break;
                case KEY_F4: Serial.print("KEY_F4"); break;
                default:
                  if(isPrintable(ch)) {
                    Serial.print((char)ch);
                  }
                break;
              }
              Serial.printf("(%d), ", ch);
              Serial.print(msg);
              Serial.println();
#endif

            temporarily_increase_led_brightness(20);
            }
        }
    }

    // Encoders
    for(int i = 0; i < NUM_ENCODERS; i++) {
      newPositionEncoders[i] = encoders[i].read();
      long difEncoder = newPositionEncoders[i] - oldPositionEncoders[i];
      int key = (difEncoder > 0) ? inc_encoder[i] : dec_encoder[i];
      if(difEncoder != 0) {
        if(i == 0) { // send as mouse
          Mouse.scroll(key);
        }      
        else if(i != 0) { // send as keyboard
          Keyboard.press(key);
          delay(KEY_PRESS_TIME);
          Keyboard.release(key);
        }

        temporarily_increase_led_brightness(20);
        oldPositionEncoders[i] = newPositionEncoders[i]; 
            
#ifdef DEBUG
        Serial.printf("encoder[%d]: key=", i);
        switch(key) {
          case KEY_HOME: Serial.print("KEY_HOME"); break;
          case KEY_END: Serial.print("KEY_END"); break;
          case KEY_PAGE_UP: Serial.print("KEY_PAGE_UP"); break;
          case KEY_PAGE_DOWN: Serial.print("KEY_PAGE_DOWN"); break;
          case KEY_RIGHT: Serial.print("KEY_RIGHT"); break;
          case KEY_LEFT: Serial.print("KEY_LEFT"); break;
          case KEY_UP: Serial.print("KEY_UP"); break;
          case KEYPAD_PLUS: Serial.print("KEYPAD_PLUS"); break;
          case KEYPAD_MINUS: Serial.print("KEYPAD_MINUS"); break;
          case -1: Serial.print("MOUSE UP"); break;
          case 1: Serial.print("MOUSE DOWN"); break;
          default: Serial.print(key); break;
        }
        Serial.println();
#endif
      }
    }


  // ====== Potentiometers ======

  for(unsigned i = 0; i < NUM_POTENTIOMETERS; i++) {
    potentiometersValues[i] = analogRead(potentiometersPins[i]);
    if(abs(potentiometersValues[i] - potentiometersOldValues[i]) > potentiometerDelta) {    
#ifdef DEBUG
      Serial.printf("potentiometersValues[%d]: %d\n", i, potentiometersValues[i]);
#endif

      switch(i) {
        case 0: Joystick.X(potentiometersValues[i] * 64); break;
        case 1: Joystick.Y(potentiometersValues[i] * 64); break;
        case 2: Joystick.Z(potentiometersValues[i] * 64); break;
        case 3: Joystick.Xrotate(potentiometersValues[i] * 64); break;
        case 4: Joystick.Yrotate(potentiometersValues[i] * 64); break;
        case 5: Joystick.Zrotate(potentiometersValues[i] * 64); break;
        case 6: Joystick.slider(1, potentiometersValues[i] * 64); break;
      }

      potentiometersOldValues[i] = potentiometersValues[i];
      temporarily_increase_led_brightness(20);
    }
  }   
}  // End loop

void temporarily_increase_led_brightness(uint32_t msec) {
      analogWrite(ledPin, 100); 
      delay(msec);
      analogWrite(ledPin,   5);  
}

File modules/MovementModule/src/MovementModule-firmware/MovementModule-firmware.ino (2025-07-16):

/*
||
|| @file firmware.ino
|| @author Luis Alejandro Bernal Romero (Aztlek)
|| @description
|| | This firmware is for the "Movement Module" of the "Modular Cockpit"
|| | @see Power Module: https://github.com/aztlek/ModularCockpit/tree/main/modules/MovementModule
|| | @see Modular Cockpit: https://github.com/aztlek/ModularCockpit.
|| #
|| 
|| @license
|| | Copyright (C) 2020 Luis Alejandro Bernal Romero (Aztlek)
|| | 
|| | This program is free software: you can redistribute it and/or modify
|| | it under the terms of the GNU General Public License as published by
|| | the Free Software Foundation, either version 3 of the License, or
|| | (at your option) any later version.
|| | 
|| | This program is distributed in the hope that it will be useful,
|| | but WITHOUT ANY WARRANTY; without even the implied warranty of
|| | MERCHANTABILITY or FITNESS FOR A PARTICULAR PURPOSE.  See the
|| | GNU General Public License for more details.
|| | 
|| | You should have received a copy of the GNU General Public License
|| | along with this program.  If not, see <http://www.gnu.org/licenses/>.
|| #
||
*/

#include <Keypad.h>
#include <Bounce.h>
#include <Encoder.h>

// #define DEBUG

// ====== Keypad ======

const byte NUMROWS = 3;
const byte NUMCOLS = 4;
char keys[NUMROWS][NUMCOLS] = {
  {  1,  2,  3,   4},
  {  5,  6,  7,   8},
  {  9, 10,  0,   0}
};

byte rowPins[NUMROWS] = { 5, 4, 3};
byte colPins[NUMCOLS] = { 9, 8, 7, 6};

Keypad kpd = Keypad( makeKeymap(keys), rowPins, colPins, NUMROWS, NUMCOLS );

// ====== Encoders ======

const byte NUMENCODERS = 0;
Encoder encoders[NUMENCODERS] = {
  // Encoder(  7,  8),
  // Encoder(  9, 10),
};

long oldPositionEncoders[NUMENCODERS];
long newPositionEncoders[NUMENCODERS];
char encodersKeys[NUMENCODERS * 2] = {
    // 6, 7,
    // 8, 9,
};

// ====== Toggle Switchs ======

#define NUM_TOGGLE_SWITCHS 1
Bounce toggle_switchs[NUM_TOGGLE_SWITCHS] = {
  Bounce(10, 10),
};

char keys_toggle_switchs[NUM_TOGGLE_SWITCHS * 2] = {
  11, 12,
};


// ====== Multi Switch ======

#define NUM_MULTI_SWITCHS 0
#define NUM_POS_MULTI_SWITCHS 3
Bounce multi_switchs[NUM_MULTI_SWITCHS][NUM_POS_MULTI_SWITCHS] = {
  // { Bounce(7, 10),  Bounce(8, 10), Bounce(9, 10), },
};

char keys_multi_switchs[NUM_MULTI_SWITCHS][NUM_POS_MULTI_SWITCHS] = {
  // { 5, 6, 7,},
};


// ====== Potentiometers ======

#define NUM_POTENTIOMETERS 2
byte potentiometersPins[NUM_POTENTIOMETERS] =
{
  A4, A5
};

int potentiometersOldValues[NUM_POTENTIOMETERS] = {
  0, 0
};
int potentiometersValues[NUM_POTENTIOMETERS] = {
  0, 0
};

const int potentiometerDelta = 8;

// ===========

#define KEY_PRESS_TIME 150
String msg;
const int ledPin = 13;

int code;

extern "C" uint32_t set_arm_clock(uint32_t frequency);

void setup() {
  set_arm_clock(24000000);
  Serial.begin(9600);

  // Led as power indicator
  temporarily_increase_led_brightness(1000);

  pinMode(10, INPUT_PULLUP);


  // ====== Potentiometers ======

  for(unsigned i = 0; i < NUM_POTENTIOMETERS; i++) {
    potentiometersValues[i] = analogRead(potentiometersPins[i]);
    potentiometersOldValues[i] = potentiometersValues[i];
  }
}

void loop() {

  // ====== Keypad ======

  if (kpd.getKeys()) {
      for (unsigned i = 0; i < LIST_MAX; i++) {
          if ( kpd.key[i].stateChanged ) {
            byte code = (byte)kpd.key[i].kchar;
            KeyState keyState = kpd.key[i].kstate;
            switch (keyState) {
                case PRESSED:
                  msg = "PRESSED";
                  Joystick.button(code, 1);
                break;
                case RELEASED:
                  msg = "RELEASED";
                  Joystick.button(code, 0);
                break;
                default:
                break;
            }   
#ifdef DEBUG        
            Serial.printf("kpd.key[%d]: Key = %d ", i, code);
            Serial.println(msg);
#endif
            temporarily_increase_led_brightness(20);
          }
      }
  }


  // ====== Encoders ======

  for(int i = 0; i < NUMENCODERS; i++) {
    byte key;
    newPositionEncoders[i] = encoders[i].read();
    long difEncoder = newPositionEncoders[i] - oldPositionEncoders[i];
    if(difEncoder != 0) {
      if(difEncoder > 0) {
        key = encodersKeys[i * 2] + 1;
        Joystick.button(key, 1);
        delay(KEY_PRESS_TIME);
        Joystick.button(key, 0);
        temporarily_increase_led_brightness(20);
      }
      else if(difEncoder < 0) {
        key = encodersKeys[i * 2];
        Joystick.button(key, 1);
        delay(KEY_PRESS_TIME);
        Joystick.button(key, 0);
        temporarily_increase_led_brightness(20);
      }
      oldPositionEncoders[i] = newPositionEncoders[i]; 
  #ifdef DEBUG
      Serial.printf("encoder[%d]: %2ld: key = %d\n", i, difEncoder, key);
  #endif
    }
  }

  // ====== Toggle Switchs ======

  for(unsigned i =0; i < NUM_TOGGLE_SWITCHS; i++) {
    toggle_switchs[i].update();
  }

  for(unsigned i = 0; i < NUM_TOGGLE_SWITCHS; i++) {
    if (toggle_switchs[i].fallingEdge()) {
      code = keys_toggle_switchs[i];
      Joystick.button(code, 1);
      delay(KEY_PRESS_TIME);
      Joystick.button(code, 0);
      temporarily_increase_led_brightness(20);
#ifdef DEBUG                       
      Serial.printf("toggle_switchs[%d]: key %d\n", i, code);
#endif
    }
  }

  for(unsigned i = 0; i < NUM_TOGGLE_SWITCHS; i++) {
    if (toggle_switchs[i].risingEdge()) {
      code = keys_toggle_switchs[i + 1];
      Joystick.button(code, 1);
      delay(KEY_PRESS_TIME);
      Joystick.button(code, 0);
      temporarily_increase_led_brightness(20);
#ifdef DEBUG
      Serial.printf("toggle_switchs[%d]: key %d\n", i, code);
#endif
    }
  }


  // ====== Multi 3 Switch ======

  for(unsigned i = 0; i < NUM_MULTI_SWITCHS; i++) {
    for(unsigned j = 0; j < NUM_POS_MULTI_SWITCHS; j++) {
      multi_switchs[i][j].update();
    }
  }

  for(unsigned i = 0; i < NUM_MULTI_SWITCHS; i++) {
    for(unsigned j = 0; j < NUM_POS_MULTI_SWITCHS; j++) {
      if (multi_switchs[i][j].fallingEdge()) {
        code = keys_multi_switchs[i][j];
        Joystick.button(code, 1);
        delay(KEY_PRESS_TIME);
        Joystick.button(code, 0);
        temporarily_increase_led_brightness(20);
#ifdef DEBUG                       
        Serial.printf("multi_switchs[%d][%d]: key %d\n", i, j, code);
#endif
      }
    }
  }


  // ====== Potentiometers ======

  for(unsigned i = 0; i < NUM_POTENTIOMETERS; i++) {
    potentiometersValues[i] = analogRead(potentiometersPins[i]);
    if(abs(potentiometersValues[i] - potentiometersOldValues[i]) > potentiometerDelta) {    
#ifdef DEBUG
      Serial.printf("potentiometersValues[%d]: %d\n", i, potentiometersValues[i]);
#endif
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

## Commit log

2022-12-19 Se inició el archivo de notas y se organizaron iconos e images que van ha servir para el diseño gráfico
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2022-12-19 Se agrego una introducción y el el comienzo de la explicación de entradas
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2022-12-20 Se fusionó con la versión antigua
    [NumberOfKeys_StarCitizen.ods]
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2022-12-20 Cambio menor
    [NumberOfKeys_StarCitizen.ods]
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2022-12-20 Se documentó los 'Flight – Power' en una tabla y se documentó los totales
2022-12-20 Se creó una tabla de dos entradas con categorias ortogonales para tener una primera aproximación al diseño del panel
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2022-12-20 Se escribió una introducción al modulo y a algunos de los subtítulos
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2022-12-26 Se cambiaron algunos pies de página, se escribió en pequeña introdución y se arreglaron algunas problemas de digitación
2022-12-26 Se comabbiaron algunos keybindingd de la cámara
    [NumberOfKeys_StarCitizen.ods]
2022-12-26 Se creó la imagen del "Twidec Toggle Rocker Switch 2 Pins 2 Position On-Off Black", en su posición On como Off
2022-12-27 Se creó la imagen del "Toggle SPST Switch 2 Position On-Off", en su posición On como Off
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2022-12-27 Se pusieron capas. Se agregó una capa de makerbeam que permitió calcular exactamente donde deben estar los tornillos. Se volvió a hacer la ca frontal con la nuevas medidas scadas de MekerBeam. Se pus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
2022-12-27 Se volvió a hacer el modulo de poder de acuerdo a los cambios del modulo general. Se gregaron los encoders.
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2022-12-27 Se dibujó la tuerca que va dentor de los rieles del MakerBeam
2022-12-27 Se dibujó un knob de 15mm, que es un buen tamaño para el módulo de potencia.
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2022-12-27 Correción menor
    [NumberOfKeys_StarCitizen.ods]
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2022-12-28 Cambios menores
    [NumberOfKeys_StarCitizen.ods]
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2022-12-29 Se inició el módulo de cockpit, hay que hacer el diseño gráfico
    [NumberOfKeys_StarCitizen.ods]
2022-12-29 Se creó un panel genérico de 60mm y se cambio el nombre del panal genérico de 100mm
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2022-12-30 Se hicieron los diseños del módulo de cockpit de 100 y 60 mm
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2022-12-30 Se añadió el Módulo de Radar Scanner a las notas generales. También se generó el png del módulo.
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2022-12-30 Se cambió el nombre del archivo png del Módulo de Radar y Scanner
2022-12-30 Se corrigió el enlace a el Módulo de Radar y Scanner
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2022-12-30 Se corrigió un nombre de keybinding en "Vehicles - Missiles"
    [NumberOfKeys_StarCitizen.ods]
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2022-12-30 Se cambió el color de las letras de los botones a negro
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2022-12-31 Se modificó el título del módulo y los componentes se pusieron en su capa
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2022-12-31 Se corrigió en nombre del archivo de imagen del módulo de cámara
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2023-01-02 Se corriguieron varios cosas del módulo de 50mm de ancho
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2023-01-02 Se arregló el módulo de 80mm
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2023-01-05 Se marcaron los keybindings que ya están en algún módulo del "Buttom Box"
    [NumberOfKeys_StarCitizen.ods]
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2023-01-05 Se reorganizó la "Modules Matriz", incluyento subtítulos de las filas
    [NumberOfKeys_StarCitizen.ods]
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2023-01-06 Se adicionó el "Scanning Mode" en "Radar and Scanning Module"
    [NumberOfKeys_StarCitizen.ods]
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2023-01-06 Se actualizó a las útimos keybindings asignados
    [NumberOfKeys_StarCitizen.ods]
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2023-01-06 Se puso el "Emergency Exit Seat" en "Cockpit Module"
    [NumberOfKeys_StarCitizen.ods]
2023-01-06 Se corrigió el error de maximo y minimo en power cuando debería ser un Reset. Se creó el README.md
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2023-01-06 Se añadió en los keybindings
    [NumberOfKeys_StarCitizen.ods]
2023-01-06 Se añadió el keybinding de "Cruise Control" a "Movement Module"
    [NumberOfKeys_StarCitizen.ods]
2023-01-06 Se crearon los archivo README.MD
    [NumberOfKeys_StarCitizen.ods]
2023-01-06 Se diseñó "Weapons Module"
    [NumberOfKeys_StarCitizen.ods]
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2023-01-13 Fixed plate stop height
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2023-01-15 The drill of the toggle switch layer middle was redesigned so that it was not visible so much from the front layer
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2023-01-17 Corrected the alignment of the keys and therefore of the drills
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2023-01-17 Cut files were generated in different formats
    [2mm-White-Front_Leyer.dxf, 3mm-Black-Back_Layer.dxf, 3mm-Black-Microcontroller_Layer.dxf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]
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2023-01-18 The cuts of the new version of the "Power Module" were generated in multiple formats
    [2mm-White-Front_Leyer.dxf, 3mm-Black-Back_Layer.dxf, 3mm-Black-Microcontroller_Layer.dxf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]
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2023-01-19 Fixed a missing encoder drill in the back layer
    [2mm-White-Front_Leyer.dxf, 3mm-Black-Back_Layer.dxf, 3mm-Black-Microcontroller_Layer.dxf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]
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2023-02-02 The inventory of components was made
    [ComponentInventory.ods]
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2023-02-03 Camera module redesigned
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2023-02-04 Redesigned "Camera Module" to 155mm
2023-02-05 The space between keys of the main keyboard of the "Camera Module" was redesigned
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2023-02-05 The "Camera Module" was redesigned
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2023-02-20 Updated for next component order
    [ComponentInventory.ods]
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2023-03-13 Designed emote keys
    [NumberOfKeys_StarCitizen.ods]
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2023-04-12 Reduced microcontroller speed to just 24MHz as it is too fast to read the keypad matrix
    [firmware.ino]
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2023-04-16 Differences with version 3.18.1 of SC are established in the spreadsheet and new development areas are created accordingly.
    [NumberOfKeys_StarCitizen.ods]
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2023-04-17 Minor change
    [NumberOfKeys_StarCitizen.ods]
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2023-04-17 Redesigning the module for the USB and the encoder
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2023-04-18 Redesigned for USB drilll and new encoder drill
2023-04-18 Redesigned for the new encoder drill
2023-04-20 Updated module design
    [ComponentInventory.ods, NumberOfKeys_StarCitizen.ods]
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2023-04-25 The tables were updated with the new modules
    [ComponentInventory.ods, NumberOfKeys_StarCitizen.ods]
2023-04-28 Redesigned the module to have the hole for the USB cable in the microcontroller layer
2023-04-28 Redesigned the "Cockpit Module" to have the hole for the USB cable in the microcontroller layer
2023-04-28 Redesigned the "Mining Module" to have the hole for the USB cable in the microcontroller layer
2023-04-28 Redesigned the "Docking and Landing Module" to have the hole for the USB cable in the microcontroller layer
2023-04-28 Redesigned the "HUD Module" to have the hole for the USB cable in the microcontroller layer
2023-04-28 Redesigned the "Radar and Scanning Module" to have the hole for the USB cable in the microcontroller layer
2023-04-28 Updated the keybind of the "Social Module" in the spreadsheet
    [NumberOfKeys_StarCitizen.ods]
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2023-04-30 The drilling of the USB cable was made and the name of the bolts was corrected, in the "ModulePanel_70mmWidth.svg"
2023-05-01 Design the new "Target Cycling Module"
    [NumberOfKeys_StarCitizen.ods]
2023-05-01 Updated spreadsheets for what the "Target Cycling Module" needs
    [ComponentInventory.ods, NumberOfKeys_StarCitizen.ods]
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2023-05-02 The "Targeting Module" was designed
    [ComponentInventory.ods]
2023-05-02 Keybindings spreadsheet updated
    [NumberOfKeys_StarCitizen.ods]
2023-05-02 The "Movement Module" was redesigned
    [NumberOfKeys_StarCitizen.ods]
2023-05-03 Updated spreadsheets for what the "Movement Module" needs
    [NumberOfKeys_StarCitizen.ods]
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2023-05-03 Updated spreadsheets
    [ComponentInventory.ods, NumberOfKeys_StarCitizen.ods]
2023-05-03 Several keybinding tables were organized
    [NumberOfKeys_StarCitizen.ods]
2023-05-03 The "Salvage Module" was designed
    [NumberOfKeys_StarCitizen.ods]
2023-05-04 The "Stopwatch Module" was designed
    [NumberOfKeys_StarCitizen.ods]
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2023-07-24 Fixed 70mm template
2023-07-25 Made the "Target Cycling Module" cut file and fixed small bugs
2023-08-04 Fixed the drill of the rotary switch of the "Weapons Module"
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2025-07-14 Central Control Panel firmware fixed
    [CentralControlPanel-firmware.ino]
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2025-07-19 The Right Mouse firmware was implemented, but the Camera Module was not included because it does not work with mouse and keyboard.
    [RightControlPanel-firmware.ino]
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2025-07-27 Fixed diode scales
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2025-08-29 The docs directory was deleted and is no longer needed.´
    [ComponentInventory.ods, NumberOfKeys_StarCitizen.ods]
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
